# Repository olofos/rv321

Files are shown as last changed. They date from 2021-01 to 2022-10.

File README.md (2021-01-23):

# rv321

rv321 is an RISC-V processor implemented using 74HC series logic. Currently the RV32E base instruction set is supported. The design has been simulated using [hneemann's Digital](https://github.com/hneemann/Digital). The simulated circuit also supports the C and Zicsr extensions, though these are not fully implemented in the hardware. The circuit is highly modular, and support for these extra extensions, or for the full RV32I base instruction set, can easily be added by changing only some of the modules.

The rv321 is implemented with a [bit-serial architecture](https://en.wikipedia.org/wiki/Bit-serial_architecture) where, for example, the ALU acts on one bit at a time. This makes the CPU very slow, each instruction requires around 100 clock cycles. The benefit of this architecture is that a one bit ALU is much smaller than a 32-bit ALU and that internal data paths only require a single line instead of a big parallel bus. This makes it possible to implement various modules as individual components connected through simple cables.

## Supported Instructions

The CPU supports all the instructions of the RV32E as well as the C and Zicsr extensions. However, the instructions are not completely decoded, which means that some illegal instructions will be incorrectly interpreted as valid instructions. This mostly affect instruction encodings that are not defined in the RISC-V specification. However, a few encodings that are valid RISC-V instructions, such as `sret` and `uret` will be erroneously decoded instead of raising an illegal instruction exception, even though these instructions are illegal since code on rv321 only runs in machine mode.

## CSRs

Currently the following CSRs are implemented:

* `mstatus`
* `mepc`
* `mtvec`
* `mscratch`
* `mcause`
* `mip`
* `mie`

All other CSRs are read as zero. Note that reading from or writing to an invalid CSR does *not* cause an illegal instruction exception.

## Traps and Interrupts

# Technical Details

The rv321 CPU is microcoded with the code stored in four 128kB parallel flash ROMs. The instructions are decoded by addressing these ROMs by 10 bits of the opcode, together with a six bit step counter and a flag bit, which is used by for example the branch instructions. Each opcode is processed in a number of *steps*, which in turn consist of either one or four *clock cycles*. There are two types of clock cycles: *control cycles* and *bus cycles*. During a control cycle only the control lines are being changed, while bus cycles are used to transfer data along the various internal and external buses. A step with a control cycle is always a single cycle long, but a step with bus cycles can be either one or four cycles long. 

Internal registers are implemented using shift registers that feed back into themselves, effectively creating delay line memories. Because of this, the bus cycles always have to come in groups of 32. Most data transfers are 32 bits and thus automatically take 32 bus cycles to complete anyway. However, there are a couple of cases where a shorter data transfer has to be extended by extra bus cycles to keep the registers in sync. One such examples is storing a single byte to memory, where only 8 cycles are needed for the actual data transfer, but an additional 24 cycles are needed to keep the alignment of the registers (note that a load of an 8 bit byte would always need 32 bus cycles since we need to fill the upper 24 bit with either zeros or the sign extension of the loaded byte). A second example is when transferring a 12 bit CSR address, where a padding of 20 cycles is necessary. These extra dummy bus cycles could have been avoided by gating the bus clock to registers that are not involved in the transfer, but the current design saves a bit of complexity by not introducing extra clock gates and control lines to drive them. 

## The ALU

The ALU supports the following operations:

* Bitwise boolean operations: `and`, `or` and `xor`
* Addition and subtraction
* Comparisons: equality, signed less-than and unsigned less-than
* Logical shift left, logical shift right and arithmetic shift right

The first three sets of operations are fairly straight forward.

The shift operations are more interesting. It does not use a full 32 bit barrel shifter since this would take up quite a bit of space. Instead the HEF4557B variable length shift register is used as intermediate storage during the computation (the same type of shift register is used in several other places in the rv321 as a convenient serial-in serial-out shift register with a fairly large number of bits, but the shifter in the ALU is the only circuitry that takes advantage of the possibility to vary the length of the shift register). The computation of a value shifted left or right by `n` bits goes in several steps:

1. Use the addition circuitry of the ALU to calculate the needed shift register length: `L = 32 + n` for a left shift and `L = 32 - n` for a right shift
1. Configure the HEF4557B shift register to be `L` bits long and clear its content
1. Shift in 32 bits of input data into the shift register
1. Shift out 32 bits of output data from the shift register

If the shift register length `L` is less than 32 (as is the case for a right shift with `n > 0`) we fill the remaining bits with either zero for a logical shift, or with the top bit of the output (the sign bit) for an arithmetic shift. The sign bit is stored in an extra flip flop which is set in the previous step.

As an example let us shift `0x87654321` by 12 bits to the left

1. The length of the shift register is `L = 32 + 12 = 44`.
1. The shift register is cleared. Its content is `0x00000000000`.
1. We shift in our 32 bits of data, starting with the least significant bit. After this the content of the shift register is `0x87654321000`.
1. We shift out 32 bits of output data, starting with the least significant bit. The result is the bottom four bytes of the shift register, `0x54321000`, which is exactly the expected result. The shift register still contains `0x00000000876`, but these bits are never used.

As a second example let us take the arithmetical shift `0x87654321` by 12 bits to the right

1. The length of the shift register is `L = 32 - 12 = 20`.
1. The shift register is cleared. Its content is `0x00000`.
1. We shift in our 32 bits of data, starting with the least significant bit. After this the content of the shift register is `0x87654`. Note that the lowest 12 bits have been discarded since they did not fit in the register.
1. We shift out 32 bits of output data, starting with the least significant bit. Since the shift register now contains less than 32 bits, we repeatedly shift in the sign bit of the input, which is our case is one. The resulting output is `0xFFF87654`, which again is the expected result. The shift register is left containing `0xFFFFF`.

## Possible Optimisations

The bit-serial architecture makes the rv321 CPU very inefficient. However, there is room for optimisation of the current implementation. There are two main steps for each instruction. First the instruction is fetched and then it is executed. The fetching is exactly the same for all instructions. It would be more efficient to begin fetching the next instruction while executing the previous instruction. This would make any instruction that does not affect the program counter or access memory run faster. However, this would require a more complicated reset circuit, to ensure that the very first instruction is properly fetched, and some parts of the circuit are made simpler by the fact that each instruction has a well-defined start and end. Moreover, the program counter is currently always routed through the ALU, so that there is only one source of memory addresses. For the ALU to run simultaneously with the loading of the memory address from the program counter, a new multiplexer would need to be added.

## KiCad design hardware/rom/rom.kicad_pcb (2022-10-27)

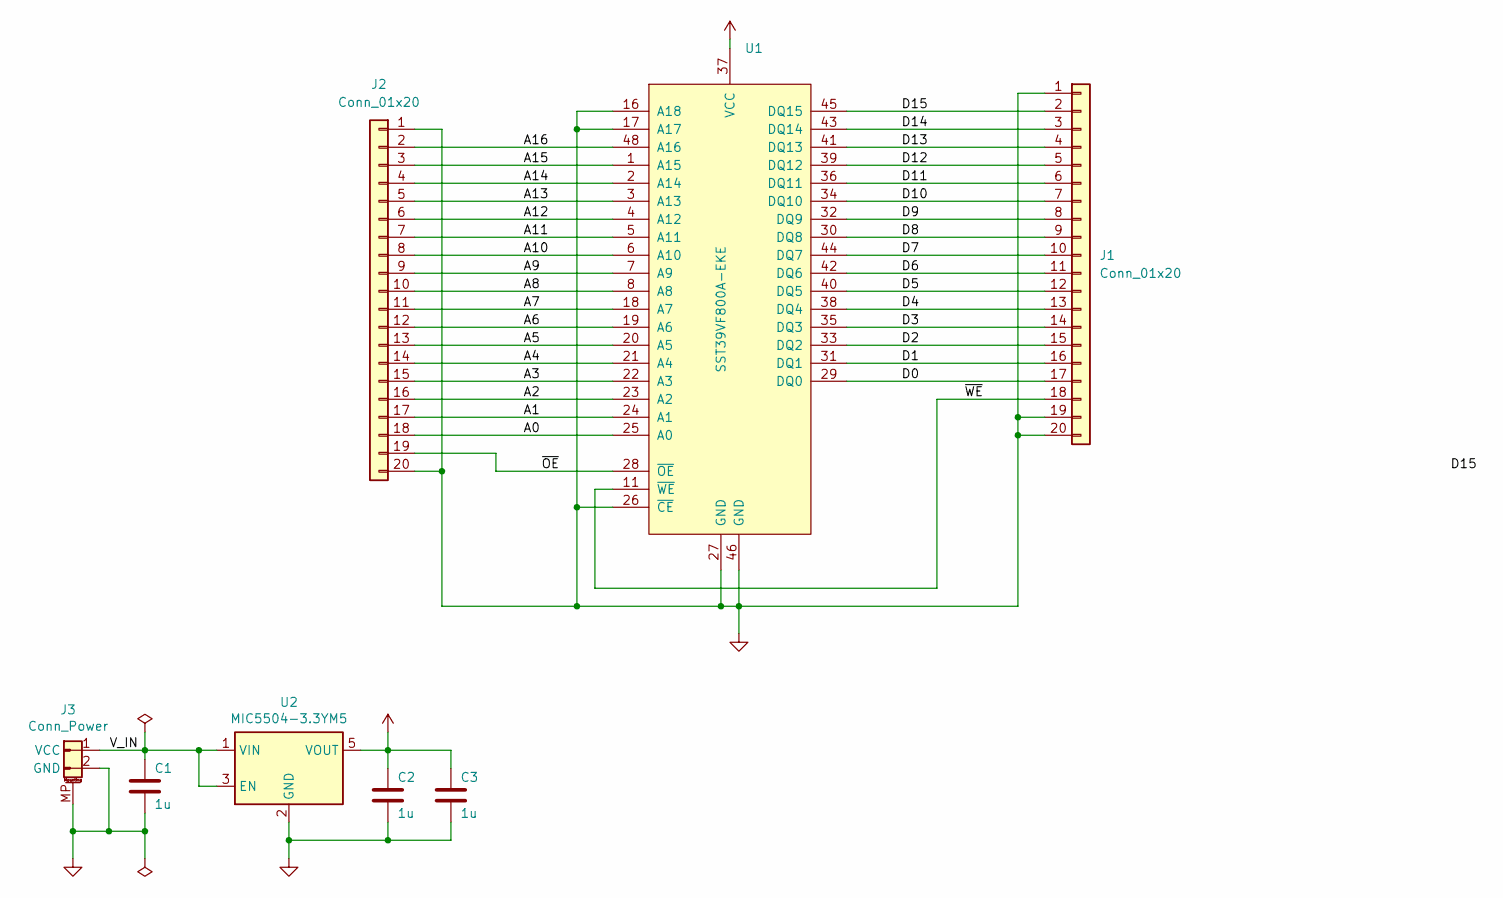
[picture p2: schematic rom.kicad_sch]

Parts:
C1, C2, C3: 1u; C_0805_2012Metric_Pad1.18x1.45mm_HandSolder
J1, J2: Conn_01x20; IDC-Header_2x10_P2.54mm_Vertical
J3: Conn_Power; JST_PH_S2B-PH-SM4-TB_1x02-1MP_P2.00mm_Horizontal
U1: SST39VF800A-EKE; TSOP-I-48_18.4x12mm_P0.5mm
U2: MIC5504-3.3YM5; SOT-23-5_HandSoldering

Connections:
/A0: J2.18, U1.25 (A0)
/A1: J2.17, U1.24 (A1)
/A2: J2.16, U1.23 (A2)
/A3: J2.15, U1.22 (A3)
/A4: J2.14, U1.21 (A4)
/A5: J2.13, U1.20 (A5)
/A6: J2.12, U1.19 (A6)
/A7: J2.11, U1.18 (A7)
/A8: J2.10, U1.8 (A8)
/A9: J2.9, U1.7 (A9)
/A10: J2.8, U1.6 (A10)
/A11: J2.7, U1.5 (A11)
/A12: J2.6, U1.4 (A12)
/A13: J2.5, U1.3 (A13)
/A14: J2.4, U1.2 (A14)
/A15: J2.3, U1.1 (A15)
/A16: J2.2, U1.48 (A16)
/D0: J1.17, U1.29 (DQ0)
/D1: J1.16, U1.31 (DQ1)
/D2: J1.15, U1.33 (DQ2)
/D3: J1.14, U1.35 (DQ3)
/D4: J1.13, U1.38 (DQ4)
/D5: J1.12, U1.40 (DQ5)
/D6: J1.11, U1.42 (DQ6)
/D7: J1.10, U1.44 (DQ7)
/D8: J1.9, U1.30 (DQ8)
/D9: J1.8, U1.32 (DQ9)
/D10: J1.7, U1.34 (DQ10)
/D11: J1.6, U1.36 (DQ11)
/D12: J1.5, U1.39 (DQ12)
/D13: J1.4, U1.41 (DQ13)
/D14: J1.3, U1.43 (DQ14)
/D15: J1.2, U1.45 (DQ15)
/V_IN: C1.2, J3.1 (VCC), U2.1 (VIN), U2.3 (EN)
/~OE: J2.19, U1.28 (~OE)
/~WE: J1.18, U1.11 (~WE)
GND: C1.1, C2.1, C3.1, J1.1, J1.19, J1.20, J2.1, J2.20, J3.2 (GND), J3.MP, U1.16 (A18), U1.17 (A17), U1.26 (~CE), U1.27 (GND), U1.46 (GND), U2.2 (GND)
VCC: C2.2, C3.2, U1.37 (VCC), U2.5 (VOUT)

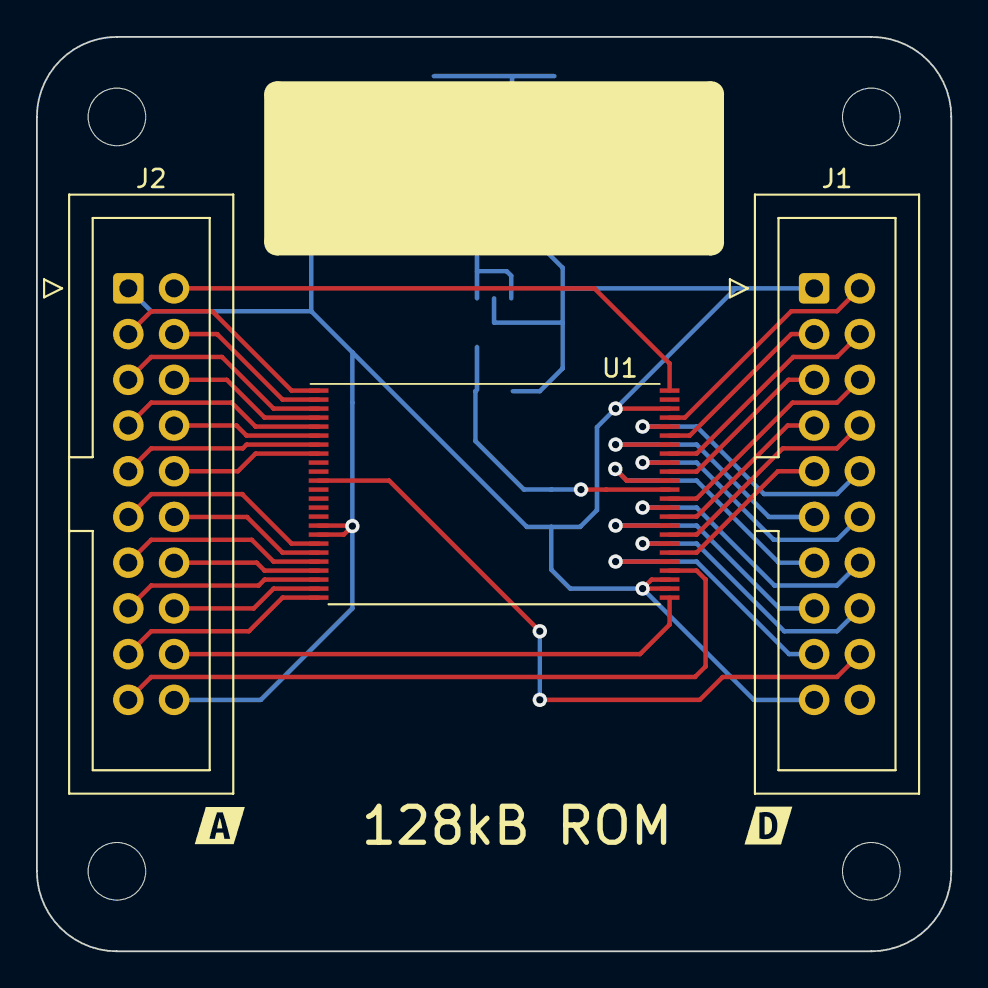
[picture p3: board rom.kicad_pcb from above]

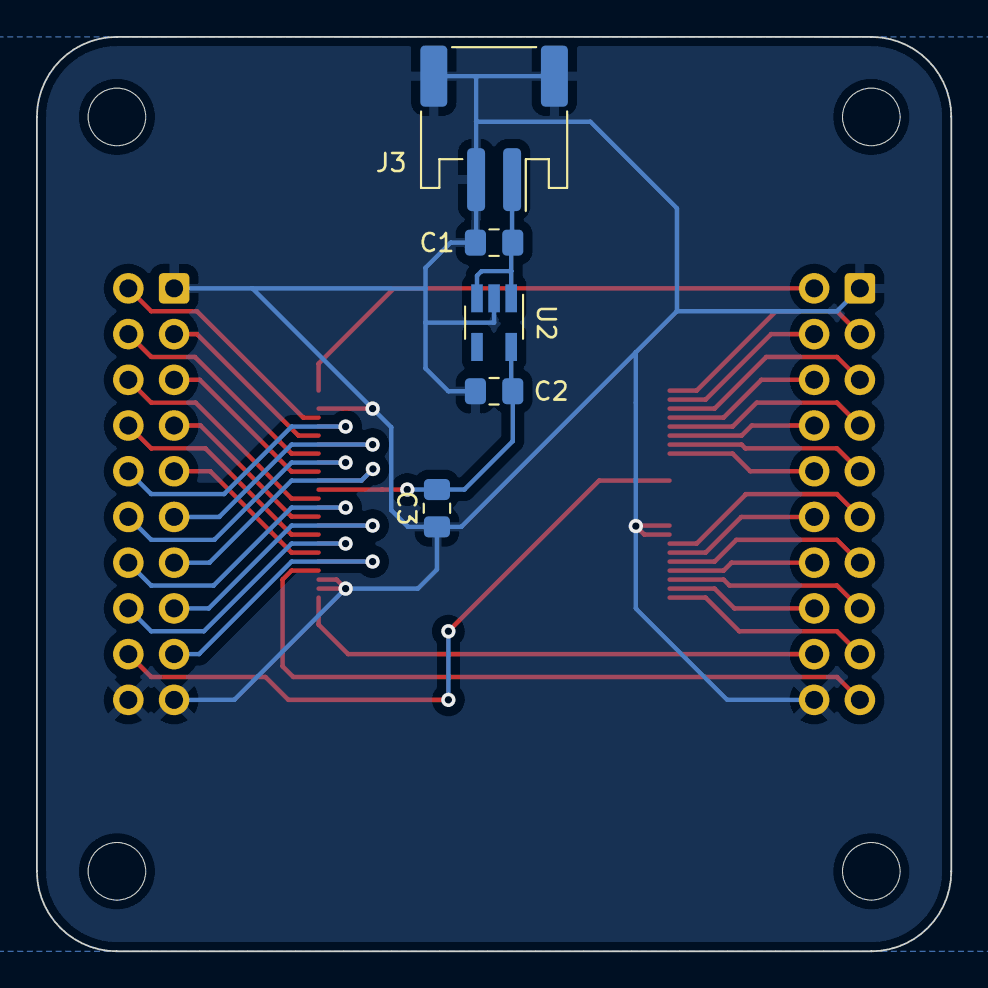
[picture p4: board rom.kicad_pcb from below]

Board: 2 copper layers, 50.8 x 50.8 mm, 10 parts (5 on the bottom side), 38 nets.

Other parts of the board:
kibuzzard-635AED85: G***; kibuzzard-635AED85
kibuzzard-635AED97: G***; kibuzzard-635AED97

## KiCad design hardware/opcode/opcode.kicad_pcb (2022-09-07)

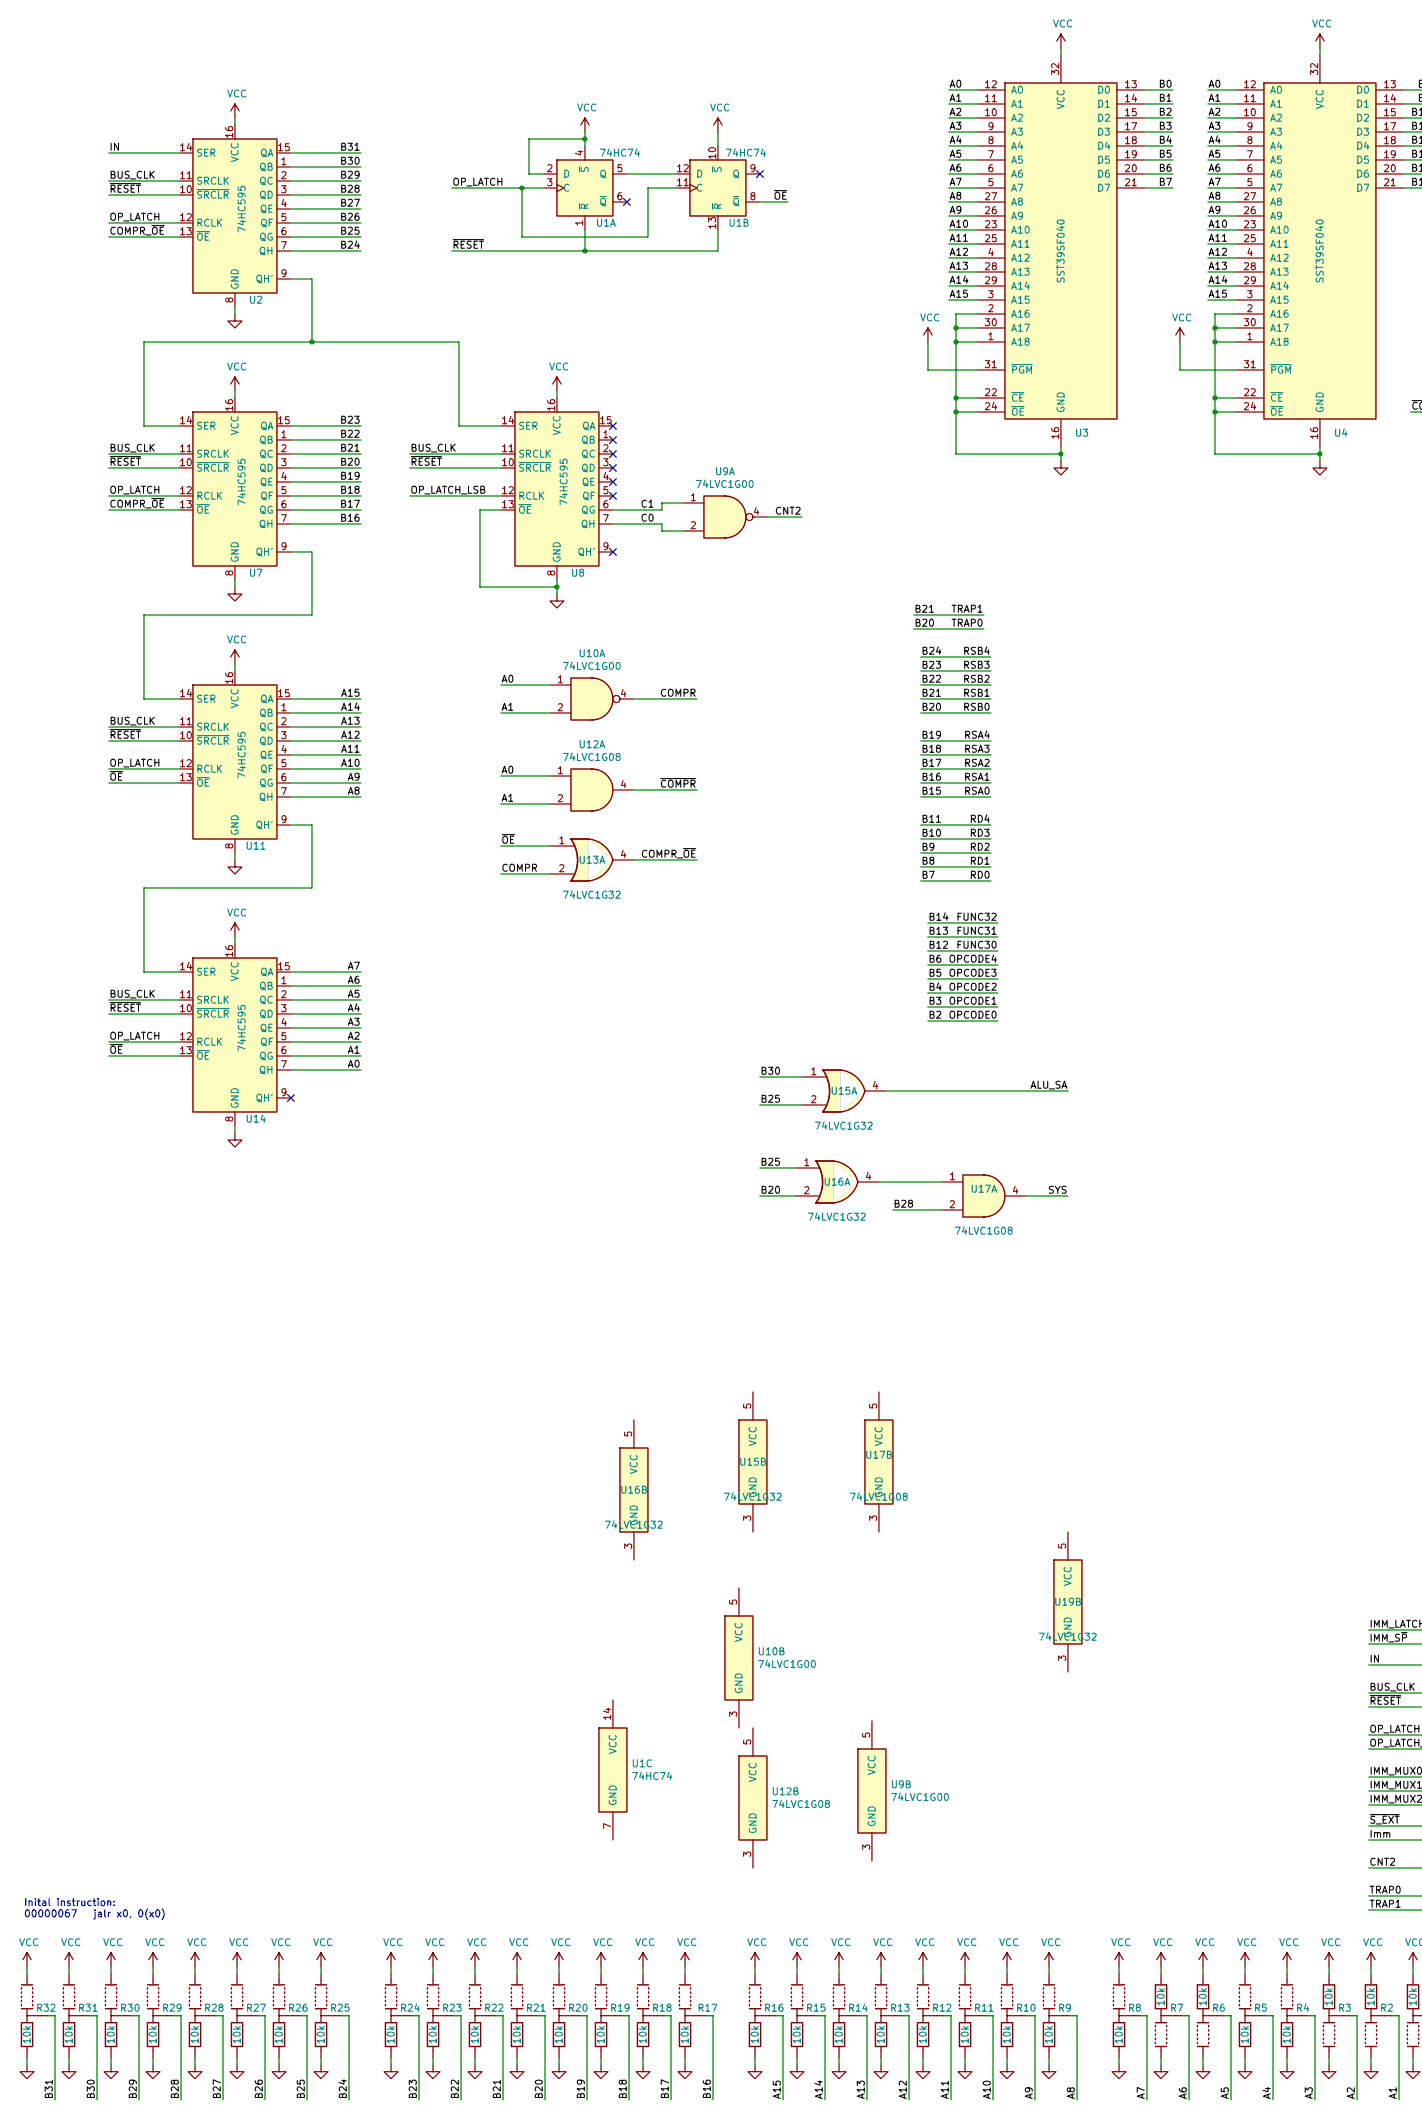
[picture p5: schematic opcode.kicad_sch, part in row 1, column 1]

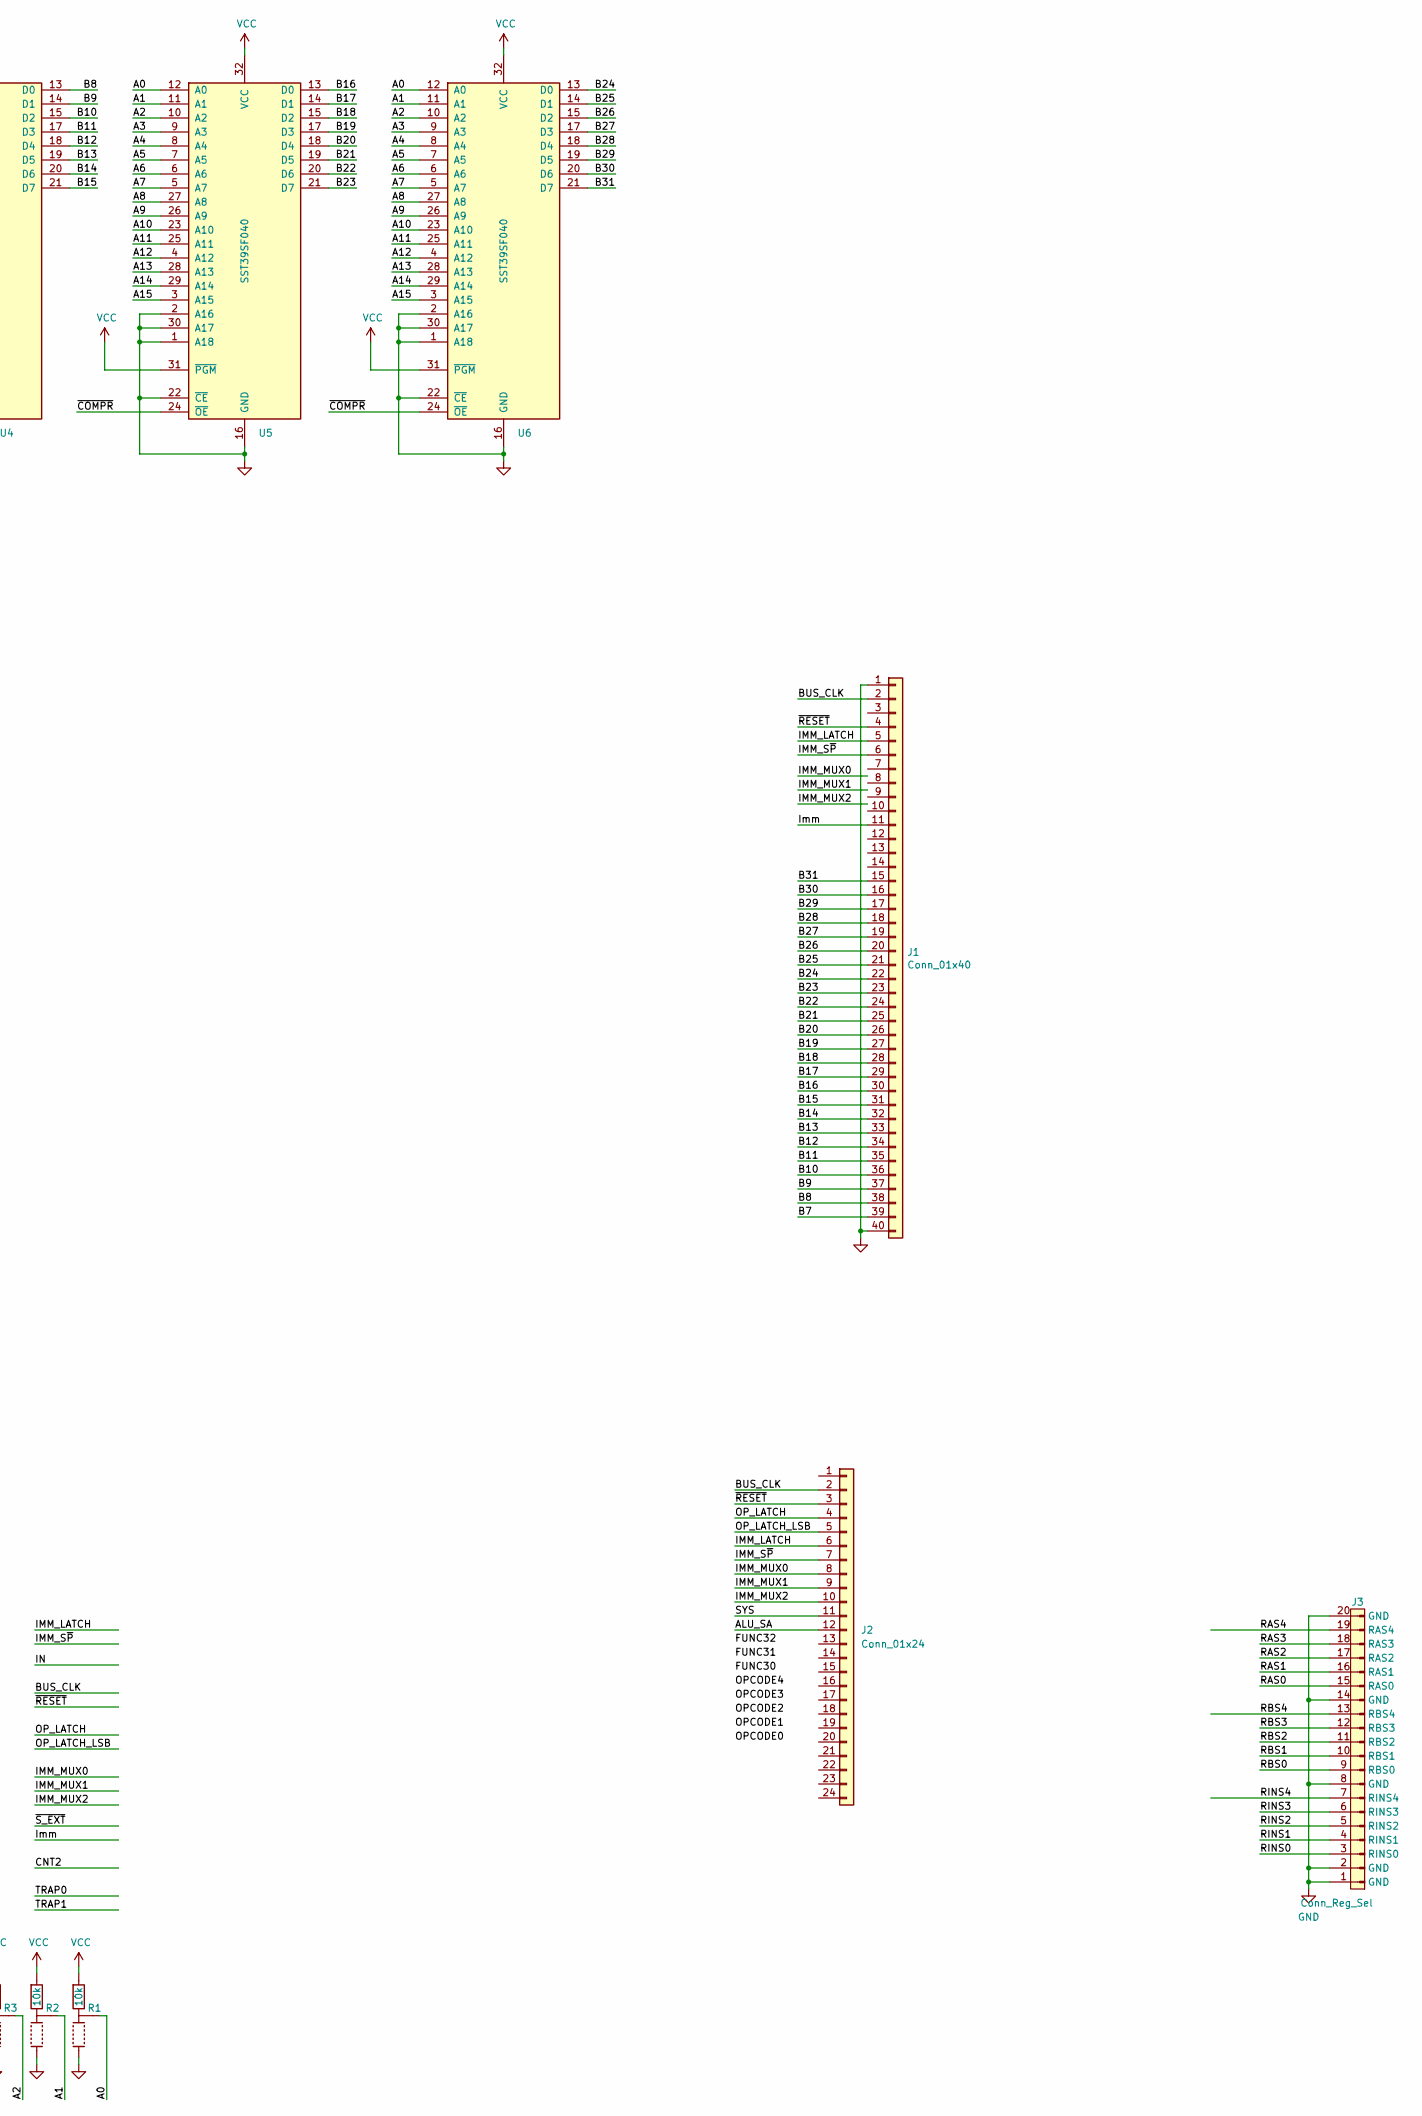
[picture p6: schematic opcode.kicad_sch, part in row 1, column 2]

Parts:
J1: Conn_01x40; IDC-Header_2x20_P2.54mm_Vertical
J2: Conn_01x24; IDC-Header_2x12_P2.54mm_Vertical
J3: Conn_Reg_Sel; IDC-Header_2x10_P2.54mm_Vertical
R1, R2, R3, R4, R5, R6, R7, R8, R9, R10, R11, R12, R13, R14, R15, R16, R17, R18, R19, R20, R21, R22, R23, R24, R25, R26, R27, R28, R29, R30, R31, R32: 10k; Jumper_3_R_0805
U1: 74HC74; SOIC-14_3.9x8.7mm_P1.27mm
U2, U7, U8, U11, U14: 74HC595; SOIC-16_3.9x9.9mm_P1.27mm
U3, U4, U5, U6: SST39SF040; PLCC-32-socket-2M-8432-11B1-RK-TP
U9, U10: 74LVC1G00; SOT-23-5_HandSoldering
U12, U17: 74LVC1G08; SOT-23-5_HandSoldering
U13, U15, U16, U19: 74LVC1G32; SOT-23-5_HandSoldering

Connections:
/A0: R1.2, U3.12 (A0), U4.12 (A0), U5.12 (A0), U6.12 (A0), U10.1, U12.1, U14.7 (QH)
/A1: R2.2, U3.11 (A1), U4.11 (A1), U5.11 (A1), U6.11 (A1), U10.2, U12.2, U14.6 (QG)
/A2: R3.2, U3.10 (A2), U4.10 (A2), U5.10 (A2), U6.10 (A2), U14.5 (QF)
/A3: R4.2, U3.9 (A3), U4.9 (A3), U5.9 (A3), U6.9 (A3), U14.4 (QE)
/A4: R5.2, U3.8 (A4), U4.8 (A4), U5.8 (A4), U6.8 (A4), U14.3 (QD)
/A5: R6.2, U3.7 (A5), U4.7 (A5), U5.7 (A5), U6.7 (A5), U14.2 (QC)
/A6: R7.2, U3.6 (A6), U4.6 (A6), U5.6 (A6), U6.6 (A6), U14.1 (QB)
/A7: R8.2, U3.5 (A7), U4.5 (A7), U5.5 (A7), U6.5 (A7), U14.15 (QA)
/A8: R9.2, U3.27 (A8), U4.27 (A8), U5.27 (A8), U6.27 (A8), U11.7 (QH)
/A9: R10.2, U3.26 (A9), U4.26 (A9), U5.26 (A9), U6.26 (A9), U11.6 (QG)
/A10: R11.2, U3.23 (A10), U4.23 (A10), U5.23 (A10), U6.23 (A10), U11.5 (QF)
/A11: R12.2, U3.25 (A11), U4.25 (A11), U5.25 (A11), U6.25 (A11), U11.4 (QE)
/A12: R13.2, U3.4 (A12), U4.4 (A12), U5.4 (A12), U6.4 (A12), U11.3 (QD)
/A13: R14.2, U3.28 (A13), U4.28 (A13), U5.28 (A13), U6.28 (A13), U11.2 (QC)
/A14: R15.2, U3.29 (A14), U4.29 (A14), U5.29 (A14), U6.29 (A14), U11.1 (QB)
/A15: R16.2, U3.3 (A15), U4.3 (A15), U5.3 (A15), U6.3 (A15), U11.15 (QA)
/ALU_SA: J2.12, U15.4
/B0: U3.13 (D0)
/B1: U3.14 (D1)
/B2: U3.15 (D2)
/B3: U3.17 (D3)
/B4: U3.18 (D4)
/B5: U3.19 (D5)
/B6: U3.20 (D6)
/B7: J1.39, U3.21 (D7)
/B8: J1.38, U4.13 (D0)
/B9: J1.37, U4.14 (D1)
/B10: J1.36, U4.15 (D2)
/B11: J1.35, U4.17 (D3)
/B12: J1.34, U4.18 (D4)
/B13: J1.33, U4.19 (D5)
/B14: J1.32, U4.20 (D6)
/B15: J1.31, U4.21 (D7)
/B16: J1.30, R17.2, U5.13 (D0), U7.7 (QH)
/B17: J1.29, R18.2, U5.14 (D1), U7.6 (QG)
/B18: J1.28, R19.2, U5.15 (D2), U7.5 (QF)
/B19: J1.27, R20.2, U5.17 (D3), U7.4 (QE)
/B20: J1.26, R21.2, U5.18 (D4), U7.3 (QD), U16.2
/B21: J1.25, R22.2, U5.19 (D5), U7.2 (QC)
/B22: J1.24, R23.2, U5.20 (D6), U7.1 (QB)
/B23: J1.23, R24.2, U5.21 (D7), U7.15 (QA)
/B24: J1.22, R25.2, U2.7 (QH), U6.13 (D0)
/B25: J1.21, R26.2, U2.6 (QG), U6.14 (D1), U15.2, U16.1
/B26: J1.20, R27.2, U2.5 (QF), U6.15 (D2)
/B27: J1.19, R28.2, U2.4 (QE), U6.17 (D3)
/B28: J1.18, R29.2, U2.3 (QD), U6.18 (D4), U17.2
/B29: J1.17, R30.2, U2.2 (QC), U6.19 (D5)
/B30: J1.16, R31.2, U2.1 (QB), U6.20 (D6), U15.1
/B31: J1.15, R32.2, U2.15 (QA), U6.21 (D7)
/BUS_CLK: J1.2, J2.2, U2.11 (SRCLK), U7.11 (SRCLK), U8.11 (SRCLK), U11.11 (SRCLK), U14.11 (SRCLK)
/C0: U8.7 (QH), U9.2
/C1: U8.6 (QG), U9.1
/CNT2: U9.4
/COMPR: U10.4, U13.2
/COMPR_~OE: U2.13 (~OE), U7.13 (~OE), U13.4
/IMM_LATCH: J1.5, J2.6
/IMM_MUX0: J2.8
/IMM_MUX1: J2.9
/IMM_MUX2: J2.10
/IMM_S~P: J1.6, J2.7
/IN: U2.14 (SER)
/Imm: J1.11
/OP_LATCH: J2.4, U1.3 (C), U1.11 (C), U2.12 (RCLK), U7.12 (RCLK), U11.12 (RCLK), U14.12 (RCLK)
/OP_LATCH_LSB: J2.5, U8.12 (RCLK)
/RAS0: J3.15 (RAS0)
/RAS1: J3.16 (RAS1)
/RAS2: J3.17 (RAS2)
/RAS3: J3.18 (RAS3)
/RAS4: J3.19 (RAS4)
/RBS0: J3.9 (RBS0)
/RBS1: J3.10 (RBS1)
/RBS2: J3.11 (RBS2)
/RBS3: J3.12 (RBS3)
/RBS4: J3.13 (RBS4)
/RINS0: J3.3 (RINS0)
/RINS1: J3.4 (RINS1)
/RINS2: J3.5 (RINS2)
/RINS3: J3.6 (RINS3)
/RINS4: J3.7 (RINS4)
/SYS: J2.11, U17.4
/~COMPR: U5.24 (~OE), U6.24 (~OE), U12.4
/~OE: U1.8 (~Q), U11.13 (~OE), U13.1, U14.13 (~OE)
/~RESET: J1.4, J2.3, U1.1 (~R), U1.13 (~R), U2.10 (~SRCLR), U7.10 (~SRCLR), U8.10 (~SRCLR), U11.10 (~SRCLR), U14.10 (~SRCLR)
GND: J1.1, J1.40, J3.1 (GND), J3.2 (GND), J3.8 (GND), J3.14 (GND), J3.20 (GND), R1.3, R2.3, R3.3, R4.1, R5.1, R6.3, R7.3, R8.1, R9.1, R10.1, R11.1, R12.1, R13.1, R14.1, R15.1, R16.1, R17.1, R18.1, R19.1, R20.1, R21.1, R22.1, R23.1, R24.1, R25.1, R26.1, R27.1, R28.1, R29.1, R30.1, R31.1, R32.1, U2.8 (GND), U3.1 (A18), U3.2 (A16), U3.16 (GND), U3.22 (~CE), U3.24 (~OE), U3.30 (A17), U4.1 (A18), U4.2 (A16), U4.16 (GND), U4.22 (~CE), U4.24 (~OE), U4.30 (A17), U5.1 (A18), U5.2 (A16), U5.16 (GND), U5.22 (~CE), U5.30 (A17), U6.1 (A18), U6.2 (A16), U6.16 (GND), U6.22 (~CE), U6.30 (A17), U7.8 (GND), U8.8 (GND), U8.13 (~OE), U11.8 (GND), U14.8 (GND)
unnamed: U1.5 (Q), U1.12 (D)
unnamed: U2.9 (QH'), U7.14 (SER), U8.14 (SER)
unnamed: U11.9 (QH'), U14.14 (SER)
unnamed: U7.9 (QH'), U11.14 (SER)
unnamed: U16.4, U17.1
VCC: R1.1, R2.1, R3.1, R4.3, R5.3, R6.1, R7.1, R8.3, R9.3, R10.3, R11.3, R12.3, R13.3, R14.3, R15.3, R16.3, R17.3, R18.3, R19.3, R20.3, R21.3, R22.3, R23.3, R24.3, R25.3, R26.3, R27.3, R28.3, R29.3, R30.3, R31.3, R32.3, U1.2 (D), U1.4 (~S), U1.10 (~S), U2.16 (VCC), U3.31 (~PGM), U3.32 (VCC), U4.31 (~PGM), U4.32 (VCC), U5.31 (~PGM), U5.32 (VCC), U6.31 (~PGM), U6.32 (VCC), U7.16 (VCC), U8.16 (VCC), U11.16 (VCC), U14.16 (VCC)

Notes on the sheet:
Inital instruction: 00000067 jalr x0, 0(x0)

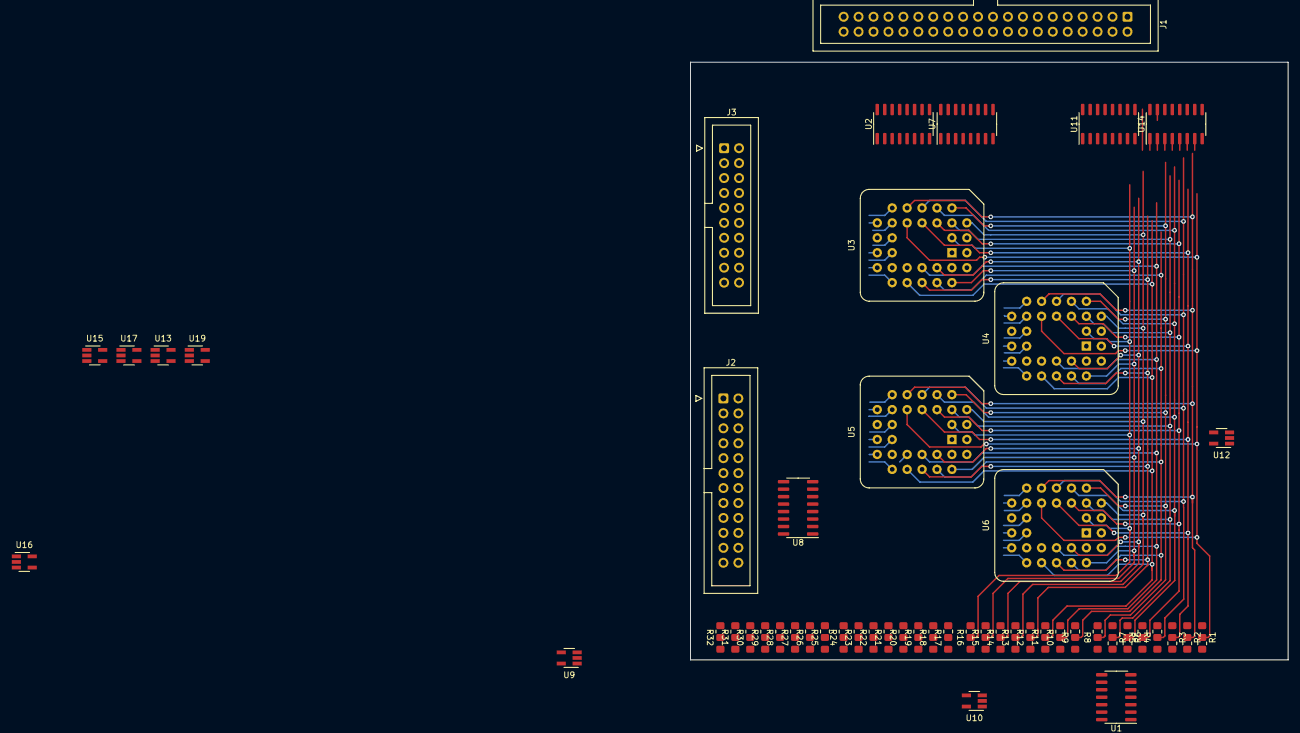
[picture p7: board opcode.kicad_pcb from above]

Board: 4 copper layers, 101.6 x 101.6 mm, 53 parts (0 on the bottom side), 62 nets.

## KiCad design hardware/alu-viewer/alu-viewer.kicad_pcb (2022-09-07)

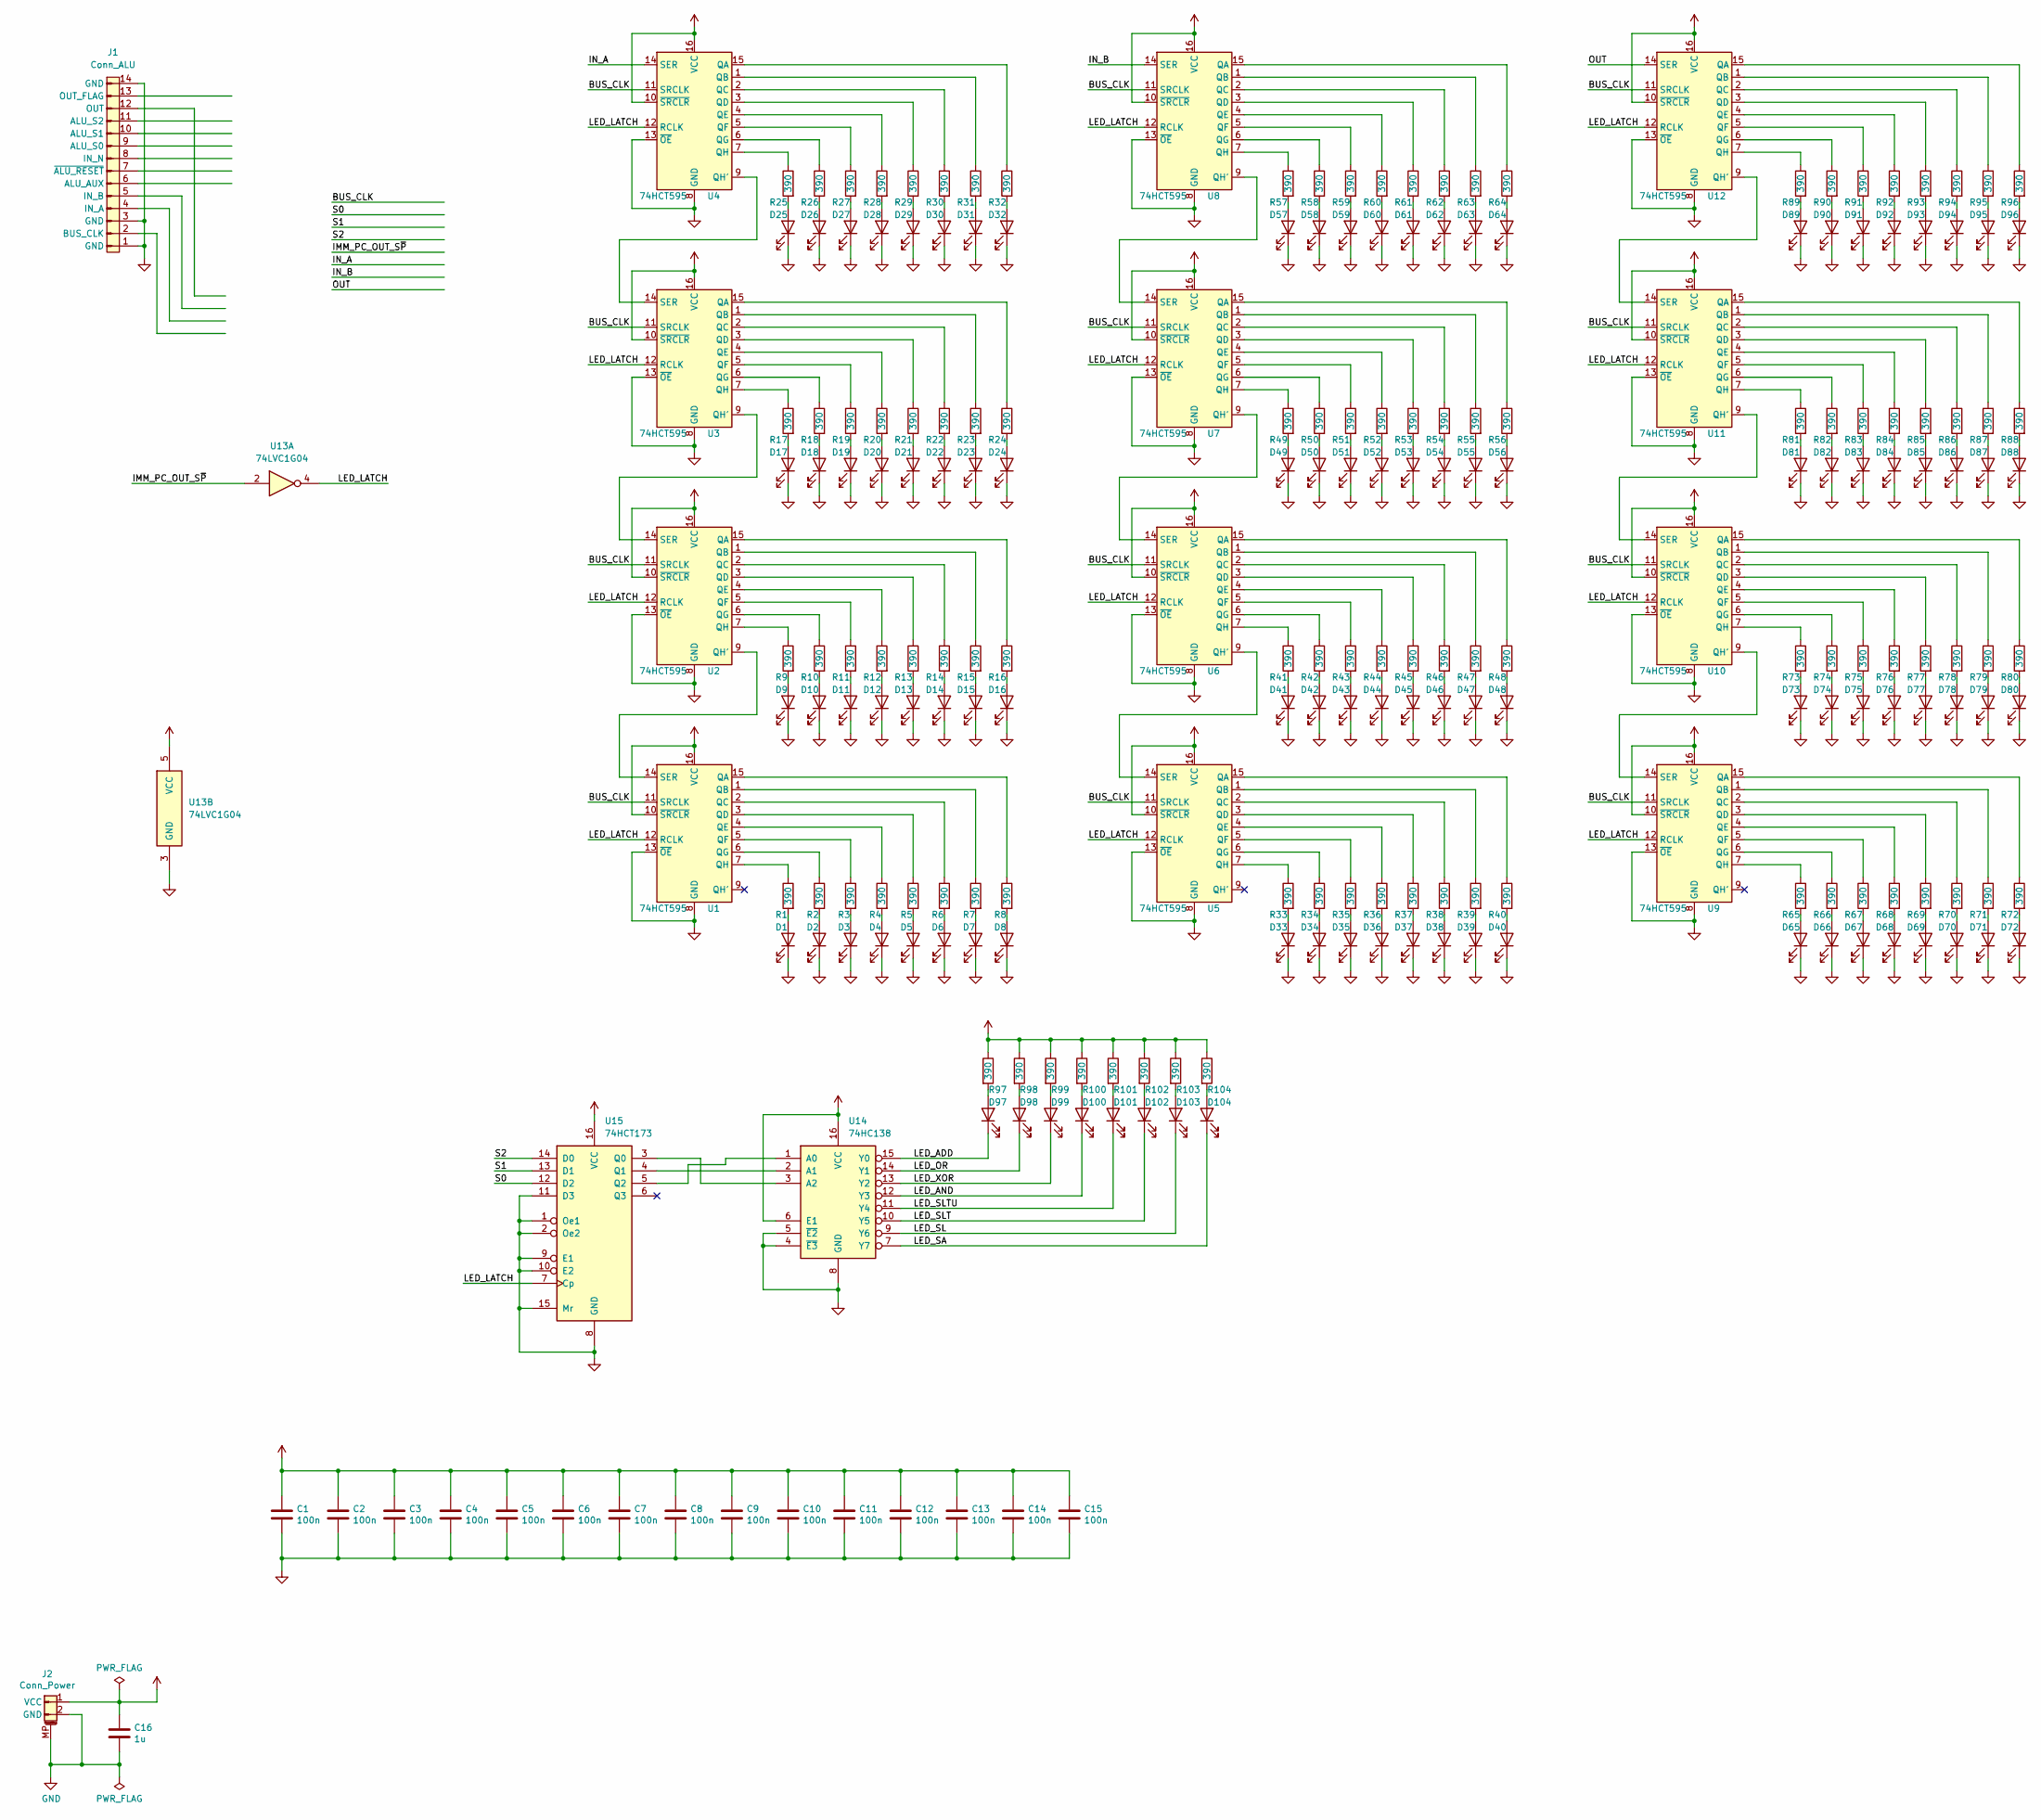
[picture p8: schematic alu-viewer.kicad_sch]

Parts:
C1, C2, C3, C4, C5, C6, C7, C8, C9, C10, C11, C12, C13, C14, C15: 100n; C_0805_2012Metric_Pad1.18x1.45mm_HandSolder
C16: 1u; C_0805_2012Metric_Pad1.18x1.45mm_HandSolder
D1, D2, D3, D4, D5, D6, D7, D8, D9, D10, D11, D12, D13, D14, D15, D16, D17, D18, D19, D20, D21, D22, D23, D24, D25, D26, D27, D28, D29, D30, D31, D32, D33, D34, D35, D36, D37, D38, D39, D40, D41, D42, D43, D44, D45, D46, D47, D48, D49, D50, D51, D52, D53, D54, D55, D56, D57, D58, D59, D60, D61, D62, D63, D64, D65, D66, D67, D68, D69, D70, D71, D72, D73, D74, D75, D76, D77, D78, D79, D80, D81, D82, D83, D84, D85, D86, D87, D88, D89, D90, D91, D92, D93, D94, D95, D96, D97, D98, D99, D100, D101, D102, D103, D104: LED; LED_0603_1608Metric
J1: Conn_ALU
J2: Conn_Power; JST_PH_S2B-PH-SM4-TB_1x02-1MP_P2.00mm_Horizontal
R1, R2, R3, R4, R5, R6, R7, R8, R9, R10, R11, R12, R13, R14, R15, R16, R17, R18, R19, R20, R21, R22, R23, R24, R25, R26, R27, R28, R29, R30, R31, R32, R33, R34, R35, R36, R37, R38, R39, R40, R41, R42, R43, R44, R45, R46, R47, R48, R49, R50, R51, R52, R53, R54, R55, R56, R57, R58, R59, R60, R61, R62, R63, R64, R65, R66, R67, R68, R69, R70, R71, R72, R73, R74, R75, R76, R77, R78, R79, R80, R81, R82, R83, R84, R85, R86, R87, R88, R89, R90, R91, R92, R93, R94, R95, R96, R97, R98, R99, R100, R101, R102, R103, R104: 390; R_0603_1608Metric
U1, U2, U3, U4, U5, U6, U7, U8, U9, U10, U11, U12: 74HCT595; SOIC-16_3.9x9.9mm_P1.27mm
U13: 74LVC1G04; SOT-23-5_HandSoldering
U14: 74HC138; SOIC-16_3.9x9.9mm_P1.27mm
U15: 74HCT173; SOIC-16_3.9x9.9mm_P1.27mm

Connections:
/BUS_CLK: U1.11 (SRCLK), U2.11 (SRCLK), U3.11 (SRCLK), U4.11 (SRCLK), U5.11 (SRCLK), U6.11 (SRCLK), U7.11 (SRCLK), U8.11 (SRCLK), U9.11 (SRCLK), U10.11 (SRCLK), U11.11 (SRCLK), U12.11 (SRCLK)
/IMM_PC_OUT_S~P: U13.2
/IN_A: U4.14 (SER)
/IN_B: U8.14 (SER)
/LED_ADD: D97.1 (K), U14.15 (Y0)
/LED_AND: D100.1 (K), U14.12 (Y3)
/LED_LATCH: U1.12 (RCLK), U2.12 (RCLK), U3.12 (RCLK), U4.12 (RCLK), U5.12 (RCLK), U6.12 (RCLK), U7.12 (RCLK), U8.12 (RCLK), U9.12 (RCLK), U10.12 (RCLK), U11.12 (RCLK), U12.12 (RCLK), U13.4, U15.7 (Cp)
/LED_OR: D98.1 (K), U14.14 (Y1)
/LED_SA: D104.1 (K), U14.7 (Y7)
/LED_SL: D103.1 (K), U14.9 (Y6)
/LED_SLT: D102.1 (K), U14.10 (Y5)
/LED_SLTU: D101.1 (K), U14.11 (Y4)
/LED_XOR: D99.1 (K), U14.13 (Y2)
/OUT: U12.14 (SER)
/S0: U15.12 (D2)
/S1: U15.13 (D1)
/S2: U15.14 (D0)
GND: C1.2, C2.2, C3.2, C4.2, C5.2, C6.2, C7.2, C8.2, C9.2, C10.2, C11.2, C12.2, C13.2, C14.2, C15.2, C16.2, D1.1 (K), D2.1 (K), D3.1 (K), D4.1 (K), D5.1 (K), D6.1 (K), D7.1 (K), D8.1 (K), D9.1 (K), D10.1 (K), D11.1 (K), D12.1 (K), D13.1 (K), D14.1 (K), D15.1 (K), D16.1 (K), D17.1 (K), D18.1 (K), D19.1 (K), D20.1 (K), D21.1 (K), D22.1 (K), D23.1 (K), D24.1 (K), D25.1 (K), D26.1 (K), D27.1 (K), D28.1 (K), D29.1 (K), D30.1 (K), D31.1 (K), D32.1 (K), D33.1 (K), D34.1 (K), D35.1 (K), D36.1 (K), D37.1 (K), D38.1 (K), D39.1 (K), D40.1 (K), D41.1 (K), D42.1 (K), D43.1 (K), D44.1 (K), D45.1 (K), D46.1 (K), D47.1 (K), D48.1 (K), D49.1 (K), D50.1 (K), D51.1 (K), D52.1 (K), D53.1 (K), D54.1 (K), D55.1 (K), D56.1 (K), D57.1 (K), D58.1 (K), D59.1 (K), D60.1 (K), D61.1 (K), D62.1 (K), D63.1 (K), D64.1 (K), D65.1 (K), D66.1 (K), D67.1 (K), D68.1 (K), D69.1 (K), D70.1 (K), D71.1 (K), D72.1 (K), D73.1 (K), D74.1 (K), D75.1 (K), D76.1 (K), D77.1 (K), D78.1 (K), D79.1 (K), D80.1 (K), D81.1 (K), D82.1 (K), D83.1 (K), D84.1 (K), D85.1 (K), D86.1 (K), D87.1 (K), D88.1 (K), D89.1 (K), D90.1 (K), D91.1 (K), D92.1 (K), D93.1 (K), D94.1 (K), D95.1 (K), D96.1 (K), J1.1 (GND), J1.3 (GND), J1.14 (GND), J2.2 (GND), J2.MP, U1.8 (GND), U1.13 (~OE), U2.8 (GND), U2.13 (~OE), U3.8 (GND), U3.13 (~OE), U4.8 (GND), U4.13 (~OE), U5.8 (GND), U5.13 (~OE), U6.8 (GND), U6.13 (~OE), U7.8 (GND), U7.13 (~OE), U8.8 (GND), U8.13 (~OE), U9.8 (GND), U9.13 (~OE), U10.8 (GND), U10.13 (~OE), U11.8 (GND), U11.13 (~OE), U12.8 (GND), U12.13 (~OE), U13.3 (GND), U14.4 (~E3), U14.5 (~E2), U14.8 (GND), U15.1 (Oe1), U15.2 (Oe2), U15.8 (GND), U15.9 (E1), U15.10 (E2), U15.11 (D3), U15.15 (Mr)
unnamed: D1.2 (A), R1.2
unnamed: D2.2 (A), R2.2
unnamed: D3.2 (A), R3.2
unnamed: D4.2 (A), R4.2
unnamed: D5.2 (A), R5.2
unnamed: D6.2 (A), R6.2
unnamed: D7.2 (A), R7.2
unnamed: D8.2 (A), R8.2
unnamed: D9.2 (A), R9.2
unnamed: D10.2 (A), R10.2
unnamed: D11.2 (A), R11.2
unnamed: D12.2 (A), R12.2
unnamed: D13.2 (A), R13.2
unnamed: D14.2 (A), R14.2
unnamed: D15.2 (A), R15.2
unnamed: D16.2 (A), R16.2
unnamed: D17.2 (A), R17.2
unnamed: D18.2 (A), R18.2
unnamed: D19.2 (A), R19.2
unnamed: D20.2 (A), R20.2
unnamed: D21.2 (A), R21.2
unnamed: D22.2 (A), R22.2
unnamed: D23.2 (A), R23.2
unnamed: D25.2 (A), R25.2
unnamed: D26.2 (A), R26.2
unnamed: D27.2 (A), R27.2
unnamed: D28.2 (A), R28.2
unnamed: D29.2 (A), R29.2
unnamed: D30.2 (A), R30.2
unnamed: D31.2 (A), R31.2
unnamed: D33.2 (A), R33.2
unnamed: D34.2 (A), R34.2
unnamed: D35.2 (A), R35.2
unnamed: D36.2 (A), R36.2
unnamed: D37.2 (A), R37.2
unnamed: D38.2 (A), R38.2
unnamed: D39.2 (A), R39.2
unnamed: D40.2 (A), R40.2
unnamed: D41.2 (A), R41.2
unnamed: D42.2 (A), R42.2
unnamed: D43.2 (A), R43.2
unnamed: D44.2 (A), R44.2
unnamed: D45.2 (A), R45.2
unnamed: D46.2 (A), R46.2
unnamed: D47.2 (A), R47.2
unnamed: D49.2 (A), R49.2
unnamed: D50.2 (A), R50.2
unnamed: D51.2 (A), R51.2
unnamed: D52.2 (A), R52.2
unnamed: D53.2 (A), R53.2
unnamed: D54.2 (A), R54.2
unnamed: D55.2 (A), R55.2
unnamed: D56.2 (A), R56.2
unnamed: D57.2 (A), R57.2
unnamed: D58.2 (A), R58.2
unnamed: D59.2 (A), R59.2
unnamed: D60.2 (A), R60.2
unnamed: D61.2 (A), R61.2
unnamed: D62.2 (A), R62.2
unnamed: D63.2 (A), R63.2
unnamed: D64.2 (A), R64.2
unnamed: D65.2 (A), R65.2
unnamed: D66.2 (A), R66.2
unnamed: D67.2 (A), R67.2
unnamed: D68.2 (A), R68.2
unnamed: D69.2 (A), R69.2
unnamed: D70.2 (A), R70.2
unnamed: D71.2 (A), R71.2
unnamed: D73.2 (A), R73.2
unnamed: D74.2 (A), R74.2
unnamed: D75.2 (A), R75.2
unnamed: D76.2 (A), R76.2
unnamed: D77.2 (A), R77.2
unnamed: D78.2 (A), R78.2
unnamed: D79.2 (A), R79.2
unnamed: D80.2 (A), R80.2
unnamed: D81.2 (A), R81.2
unnamed: D82.2 (A), R82.2
unnamed: D83.2 (A), R83.2
unnamed: D84.2 (A), R84.2
unnamed: D85.2 (A), R85.2
unnamed: D86.2 (A), R86.2
unnamed: D87.2 (A), R87.2
unnamed: D88.2 (A), R88.2
unnamed: D89.2 (A), R89.2
unnamed: D90.2 (A), R90.2
unnamed: D91.2 (A), R91.2
unnamed: D92.2 (A), R92.2
unnamed: D93.2 (A), R93.2
unnamed: D94.2 (A), R94.2
unnamed: D95.2 (A), R95.2
unnamed: D96.2 (A), R96.2
unnamed: D97.2 (A), R97.2
unnamed: D98.2 (A), R98.2
unnamed: D99.2 (A), R99.2
unnamed: D100.2 (A), R100.2
unnamed: D101.2 (A), R101.2
unnamed: D102.2 (A), R102.2
unnamed: D103.2 (A), R103.2
unnamed: D104.2 (A), R104.2
unnamed: R9.1, U2.7 (QH)
unnamed: R10.1, U2.6 (QG)
unnamed: R11.1, U2.5 (QF)
unnamed: R12.1, U2.4 (QE)
unnamed: R13.1, U2.3 (QD)
unnamed: R14.1, U2.2 (QC)
unnamed: R15.1, U2.1 (QB)
unnamed: R16.1, U2.15 (QA)
unnamed: R17.1, U3.7 (QH)
unnamed: R18.1, U3.6 (QG)
unnamed: R19.1, U3.5 (QF)
unnamed: R20.1, U3.4 (QE)
unnamed: R21.1, U3.3 (QD)
unnamed: R22.1, U3.2 (QC)
unnamed: R23.1, U3.1 (QB)
unnamed: R24.1, U3.15 (QA)
unnamed: D24.2 (A), R24.2
unnamed: R25.1, U4.7 (QH)
unnamed: R26.1, U4.6 (QG)
unnamed: R27.1, U4.5 (QF)
unnamed: R28.1, U4.4 (QE)
unnamed: R29.1, U4.3 (QD)
unnamed: R30.1, U4.2 (QC)
unnamed: R31.1, U4.1 (QB)
unnamed: R32.1, U4.15 (QA)
unnamed: D32.2 (A), R32.2
unnamed: R33.1, U5.7 (QH)
unnamed: R34.1, U5.6 (QG)
unnamed: R35.1, U5.5 (QF)
unnamed: R36.1, U5.4 (QE)
unnamed: R37.1, U5.3 (QD)
unnamed: R38.1, U5.2 (QC)
unnamed: R39.1, U5.1 (QB)
unnamed: R40.1, U5.15 (QA)
unnamed: R41.1, U6.7 (QH)
unnamed: R42.1, U6.6 (QG)
unnamed: R43.1, U6.5 (QF)
unnamed: R44.1, U6.4 (QE)
unnamed: R45.1, U6.3 (QD)
unnamed: R46.1, U6.2 (QC)
unnamed: R47.1, U6.1 (QB)
unnamed: R48.1, U6.15 (QA)
unnamed: D48.2 (A), R48.2
unnamed: R49.1, U7.7 (QH)
unnamed: R50.1, U7.6 (QG)
unnamed: R51.1, U7.5 (QF)
unnamed: R52.1, U7.4 (QE)
unnamed: R53.1, U7.3 (QD)
unnamed: R54.1, U7.2 (QC)
unnamed: R55.1, U7.1 (QB)
unnamed: R56.1, U7.15 (QA)
unnamed: R57.1, U8.7 (QH)
unnamed: R58.1, U8.6 (QG)
unnamed: R59.1, U8.5 (QF)
unnamed: R60.1, U8.4 (QE)
unnamed: R61.1, U8.3 (QD)
unnamed: R62.1, U8.2 (QC)
unnamed: R63.1, U8.1 (QB)
unnamed: R64.1, U8.15 (QA)
unnamed: R65.1, U9.7 (QH)
unnamed: R66.1, U9.6 (QG)
unnamed: R67.1, U9.5 (QF)
unnamed: R68.1, U9.4 (QE)
unnamed: R69.1, U9.3 (QD)
unnamed: R70.1, U9.2 (QC)
unnamed: R71.1, U9.1 (QB)
unnamed: R72.1, U9.15 (QA)
unnamed: D72.2 (A), R72.2
unnamed: R73.1, U10.7 (QH)
unnamed: R74.1, U10.6 (QG)
unnamed: R75.1, U10.5 (QF)
unnamed: R76.1, U10.4 (QE)
unnamed: R77.1, U10.3 (QD)
unnamed: R78.1, U10.2 (QC)
unnamed: R79.1, U10.1 (QB)
unnamed: R80.1, U10.15 (QA)
unnamed: R81.1, U11.7 (QH)
unnamed: R82.1, U11.6 (QG)
unnamed: R83.1, U11.5 (QF)
unnamed: R84.1, U11.4 (QE)
unnamed: R85.1, U11.3 (QD)
unnamed: R86.1, U11.2 (QC)
unnamed: R87.1, U11.1 (QB)
unnamed: R88.1, U11.15 (QA)
unnamed: R89.1, U12.7 (QH)
unnamed: R90.1, U12.6 (QG)
unnamed: R91.1, U12.5 (QF)
unnamed: R92.1, U12.4 (QE)
unnamed: R93.1, U12.3 (QD)
unnamed: R94.1, U12.2 (QC)
unnamed: R95.1, U12.1 (QB)
unnamed: R96.1, U12.15 (QA)
unnamed: R7.1, U1.1 (QB)
unnamed: R6.1, U1.2 (QC)
unnamed: R5.1, U1.3 (QD)
unnamed: R4.1, U1.4 (QE)
unnamed: R3.1, U1.5 (QF)
unnamed: R2.1, U1.6 (QG)
unnamed: R1.1, U1.7 (QH)
unnamed: U1.14 (SER), U2.9 (QH')
unnamed: R8.1, U1.15 (QA)
unnamed: U2.14 (SER), U3.9 (QH')
unnamed: U3.14 (SER), U4.9 (QH')
unnamed: U5.14 (SER), U6.9 (QH')
unnamed: U6.14 (SER), U7.9 (QH')
unnamed: U7.14 (SER), U8.9 (QH')
unnamed: U9.14 (SER), U10.9 (QH')
unnamed: U10.14 (SER), U11.9 (QH')
unnamed: U11.14 (SER), U12.9 (QH')
unnamed: U14.1 (A0), U15.5 (Q2)
unnamed: U14.2 (A1), U15.4 (Q1)
unnamed: U14.3 (A2), U15.3 (Q0)
VCC: C1.1, C2.1, C3.1, C4.1, C5.1, C6.1, C7.1, C8.1, C9.1, C10.1, C11.1, C12.1, C13.1, C14.1, C15.1, C16.1, J2.1 (VCC), R97.1, R98.1, R99.1, R100.1, R101.1, R102.1, R103.1, R104.1, U1.10 (~SRCLR), U1.16 (VCC), U2.10 (~SRCLR), U2.16 (VCC), U3.10 (~SRCLR), U3.16 (VCC), U4.10 (~SRCLR), U4.16 (VCC), U5.10 (~SRCLR), U5.16 (VCC), U6.10 (~SRCLR), U6.16 (VCC), U7.10 (~SRCLR), U7.16 (VCC), U8.10 (~SRCLR), U8.16 (VCC), U9.10 (~SRCLR), U9.16 (VCC), U10.10 (~SRCLR), U10.16 (VCC), U11.10 (~SRCLR), U11.16 (VCC), U12.10 (~SRCLR), U12.16 (VCC), U13.5 (VCC), U14.6 (E1), U14.16 (VCC), U15.16 (VCC)

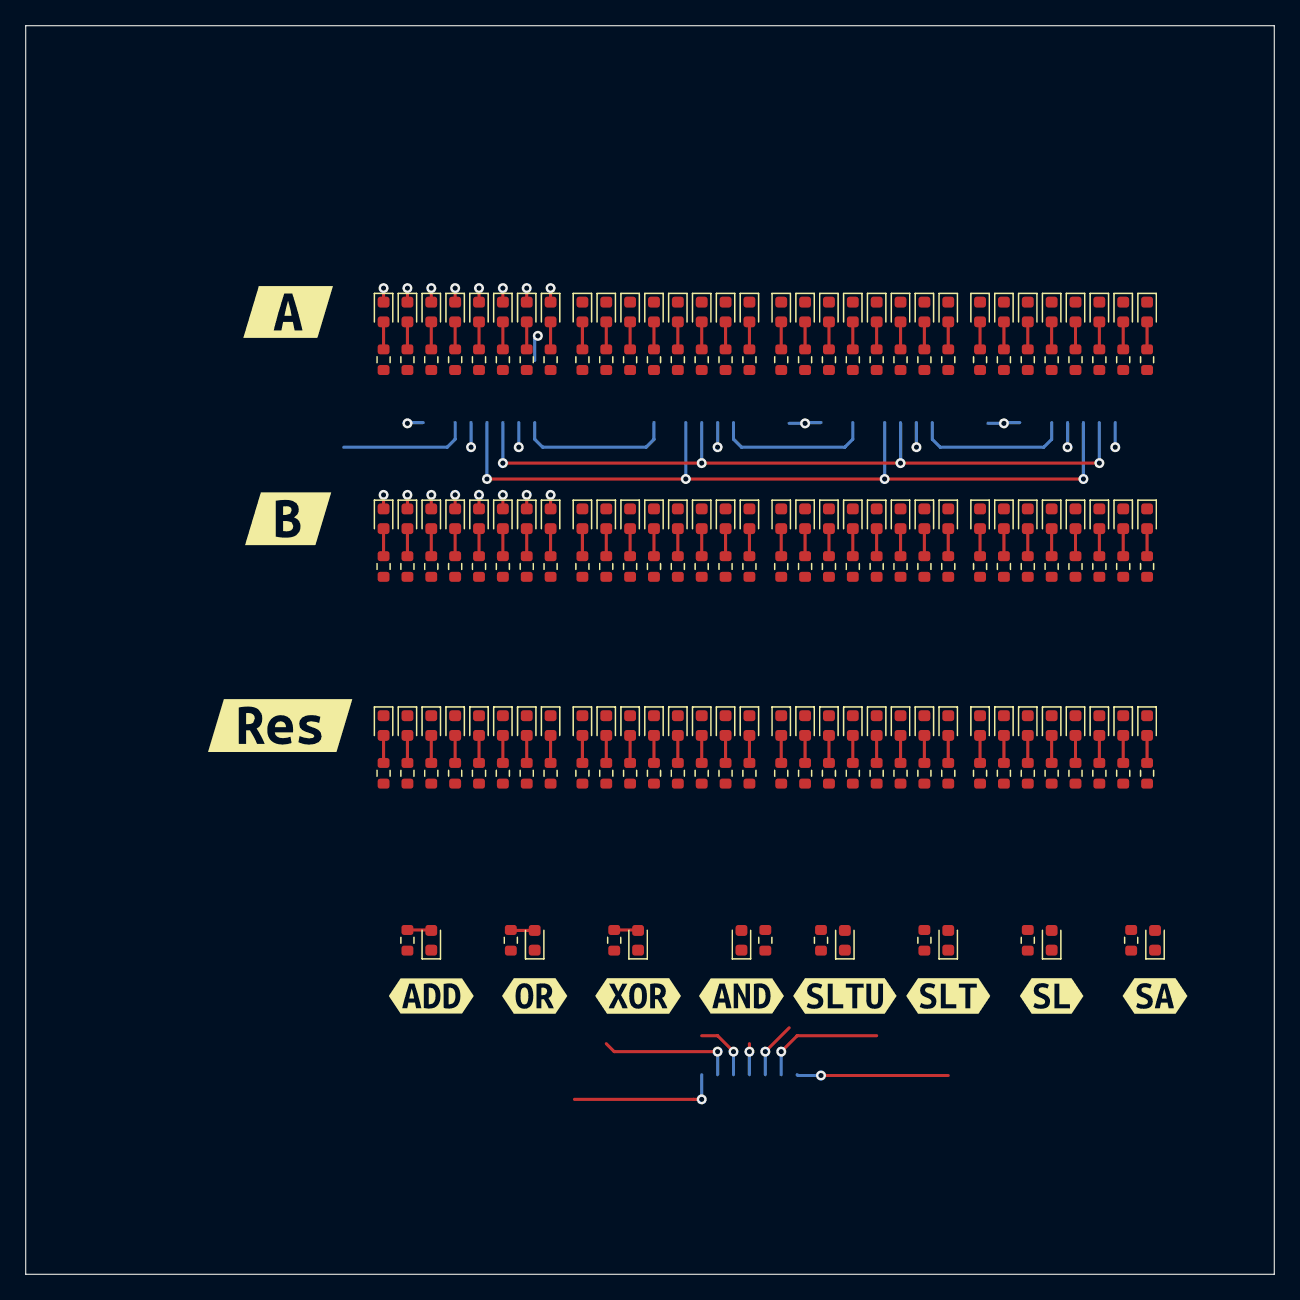
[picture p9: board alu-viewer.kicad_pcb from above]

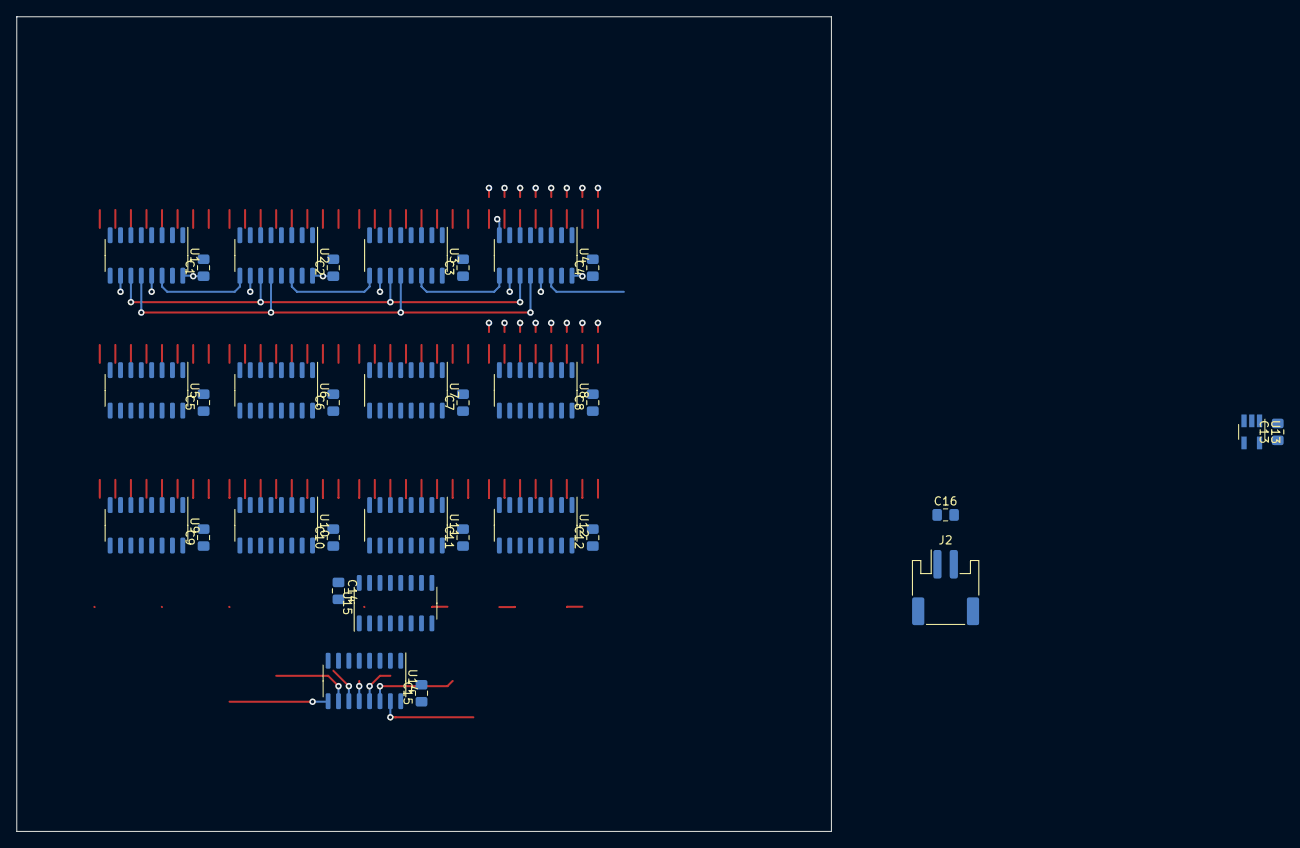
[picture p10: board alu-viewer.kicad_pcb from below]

Board: 4 copper layers, 99.7 x 99.7 mm, 251 parts (32 on the bottom side), 224 nets.

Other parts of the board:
kibuzzard-631087D5: G***; kibuzzard-631087D5
kibuzzard-631087E9: G***; kibuzzard-631087E9
kibuzzard-631088E6: G***; kibuzzard-631088E6
kibuzzard-631088FC: G***; kibuzzard-631088FC
kibuzzard-631089CA: G***; kibuzzard-631089CA
kibuzzard-6310893A: G***; kibuzzard-6310893A
kibuzzard-6310894E: G***; kibuzzard-6310894E
kibuzzard-6310895A: G***; kibuzzard-6310895A
kibuzzard-63108921: G***; kibuzzard-63108921
kibuzzard-63108965: G***; kibuzzard-63108965
kibuzzard-63108972: G***; kibuzzard-63108972

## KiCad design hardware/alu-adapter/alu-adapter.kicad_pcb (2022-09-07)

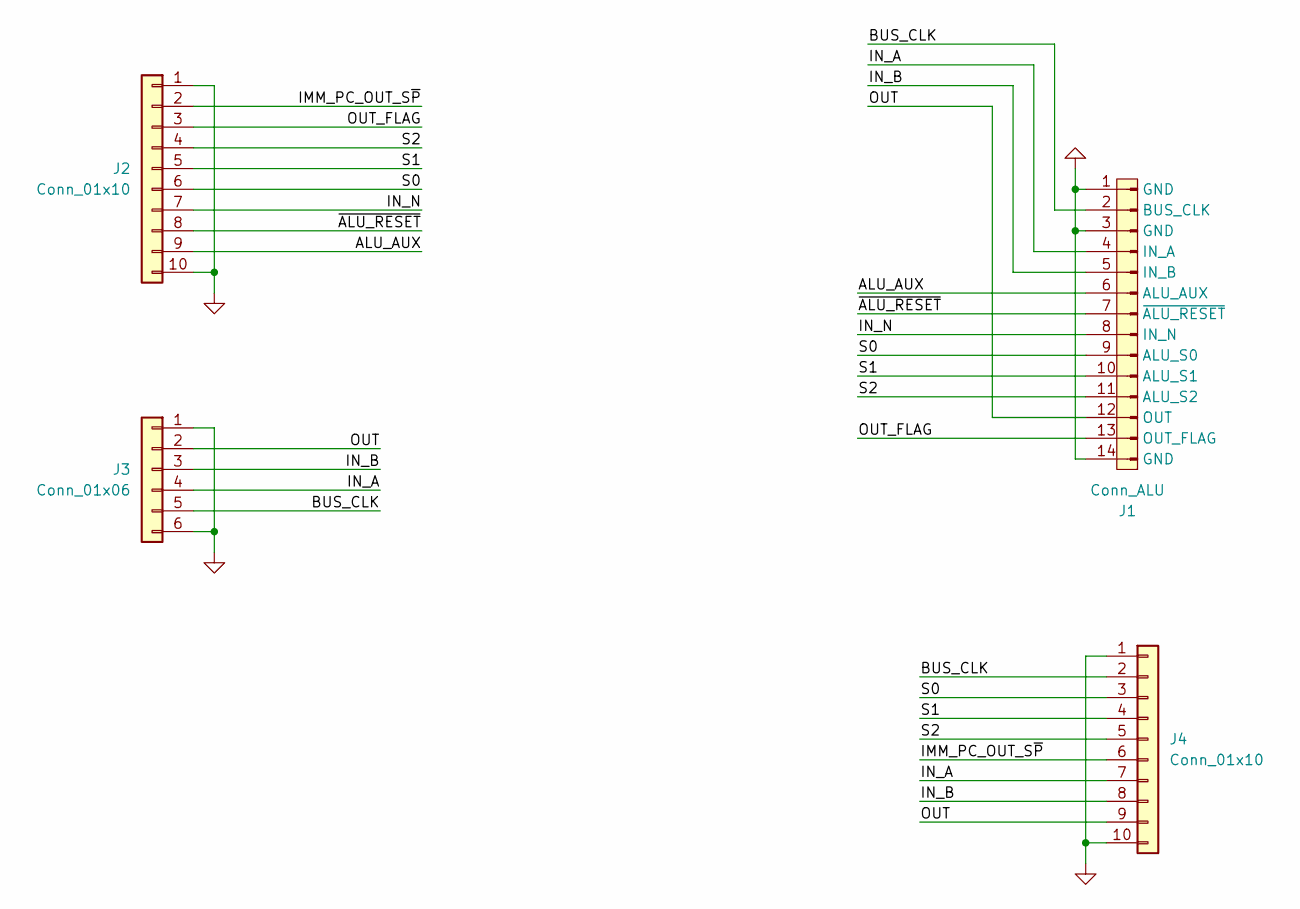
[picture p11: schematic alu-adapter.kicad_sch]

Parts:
J1: Conn_ALU; IDC-Header_2x07_P2.54mm_Vertical
J2, J4: Conn_01x10; IDC-Header_2x05_P2.54mm_Vertical
J3: Conn_01x06; IDC-Header_2x03_P2.54mm_Vertical

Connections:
/ALU_AUX: J1.6 (ALU_AUX), J2.9
/BUS_CLK: J1.2 (BUS_CLK), J3.5, J4.2
/IMM_PC_OUT_S~P: J2.2, J4.6
/IN_A: J1.4 (IN_A), J3.4, J4.7
/IN_B: J1.5 (IN_B), J3.3, J4.8
/IN_N: J1.8 (IN_N), J2.7
/OUT: J1.12 (OUT), J3.2, J4.9
/OUT_FLAG: J1.13 (OUT_FLAG), J2.3
/S0: J1.9 (ALU_S0), J2.6, J4.3
/S1: J1.10 (ALU_S1), J2.5, J4.4
/S2: J1.11 (ALU_S2), J2.4, J4.5
/~ALU_RESET: J1.7 (~ALU_RESET), J2.8
GND: J1.1 (GND), J1.3 (GND), J1.14 (GND), J2.1, J2.10, J3.1, J3.6, J4.1, J4.10

Board: 2 copper layers, 4 parts (0 on the bottom side), 13 nets, no tracks yet.

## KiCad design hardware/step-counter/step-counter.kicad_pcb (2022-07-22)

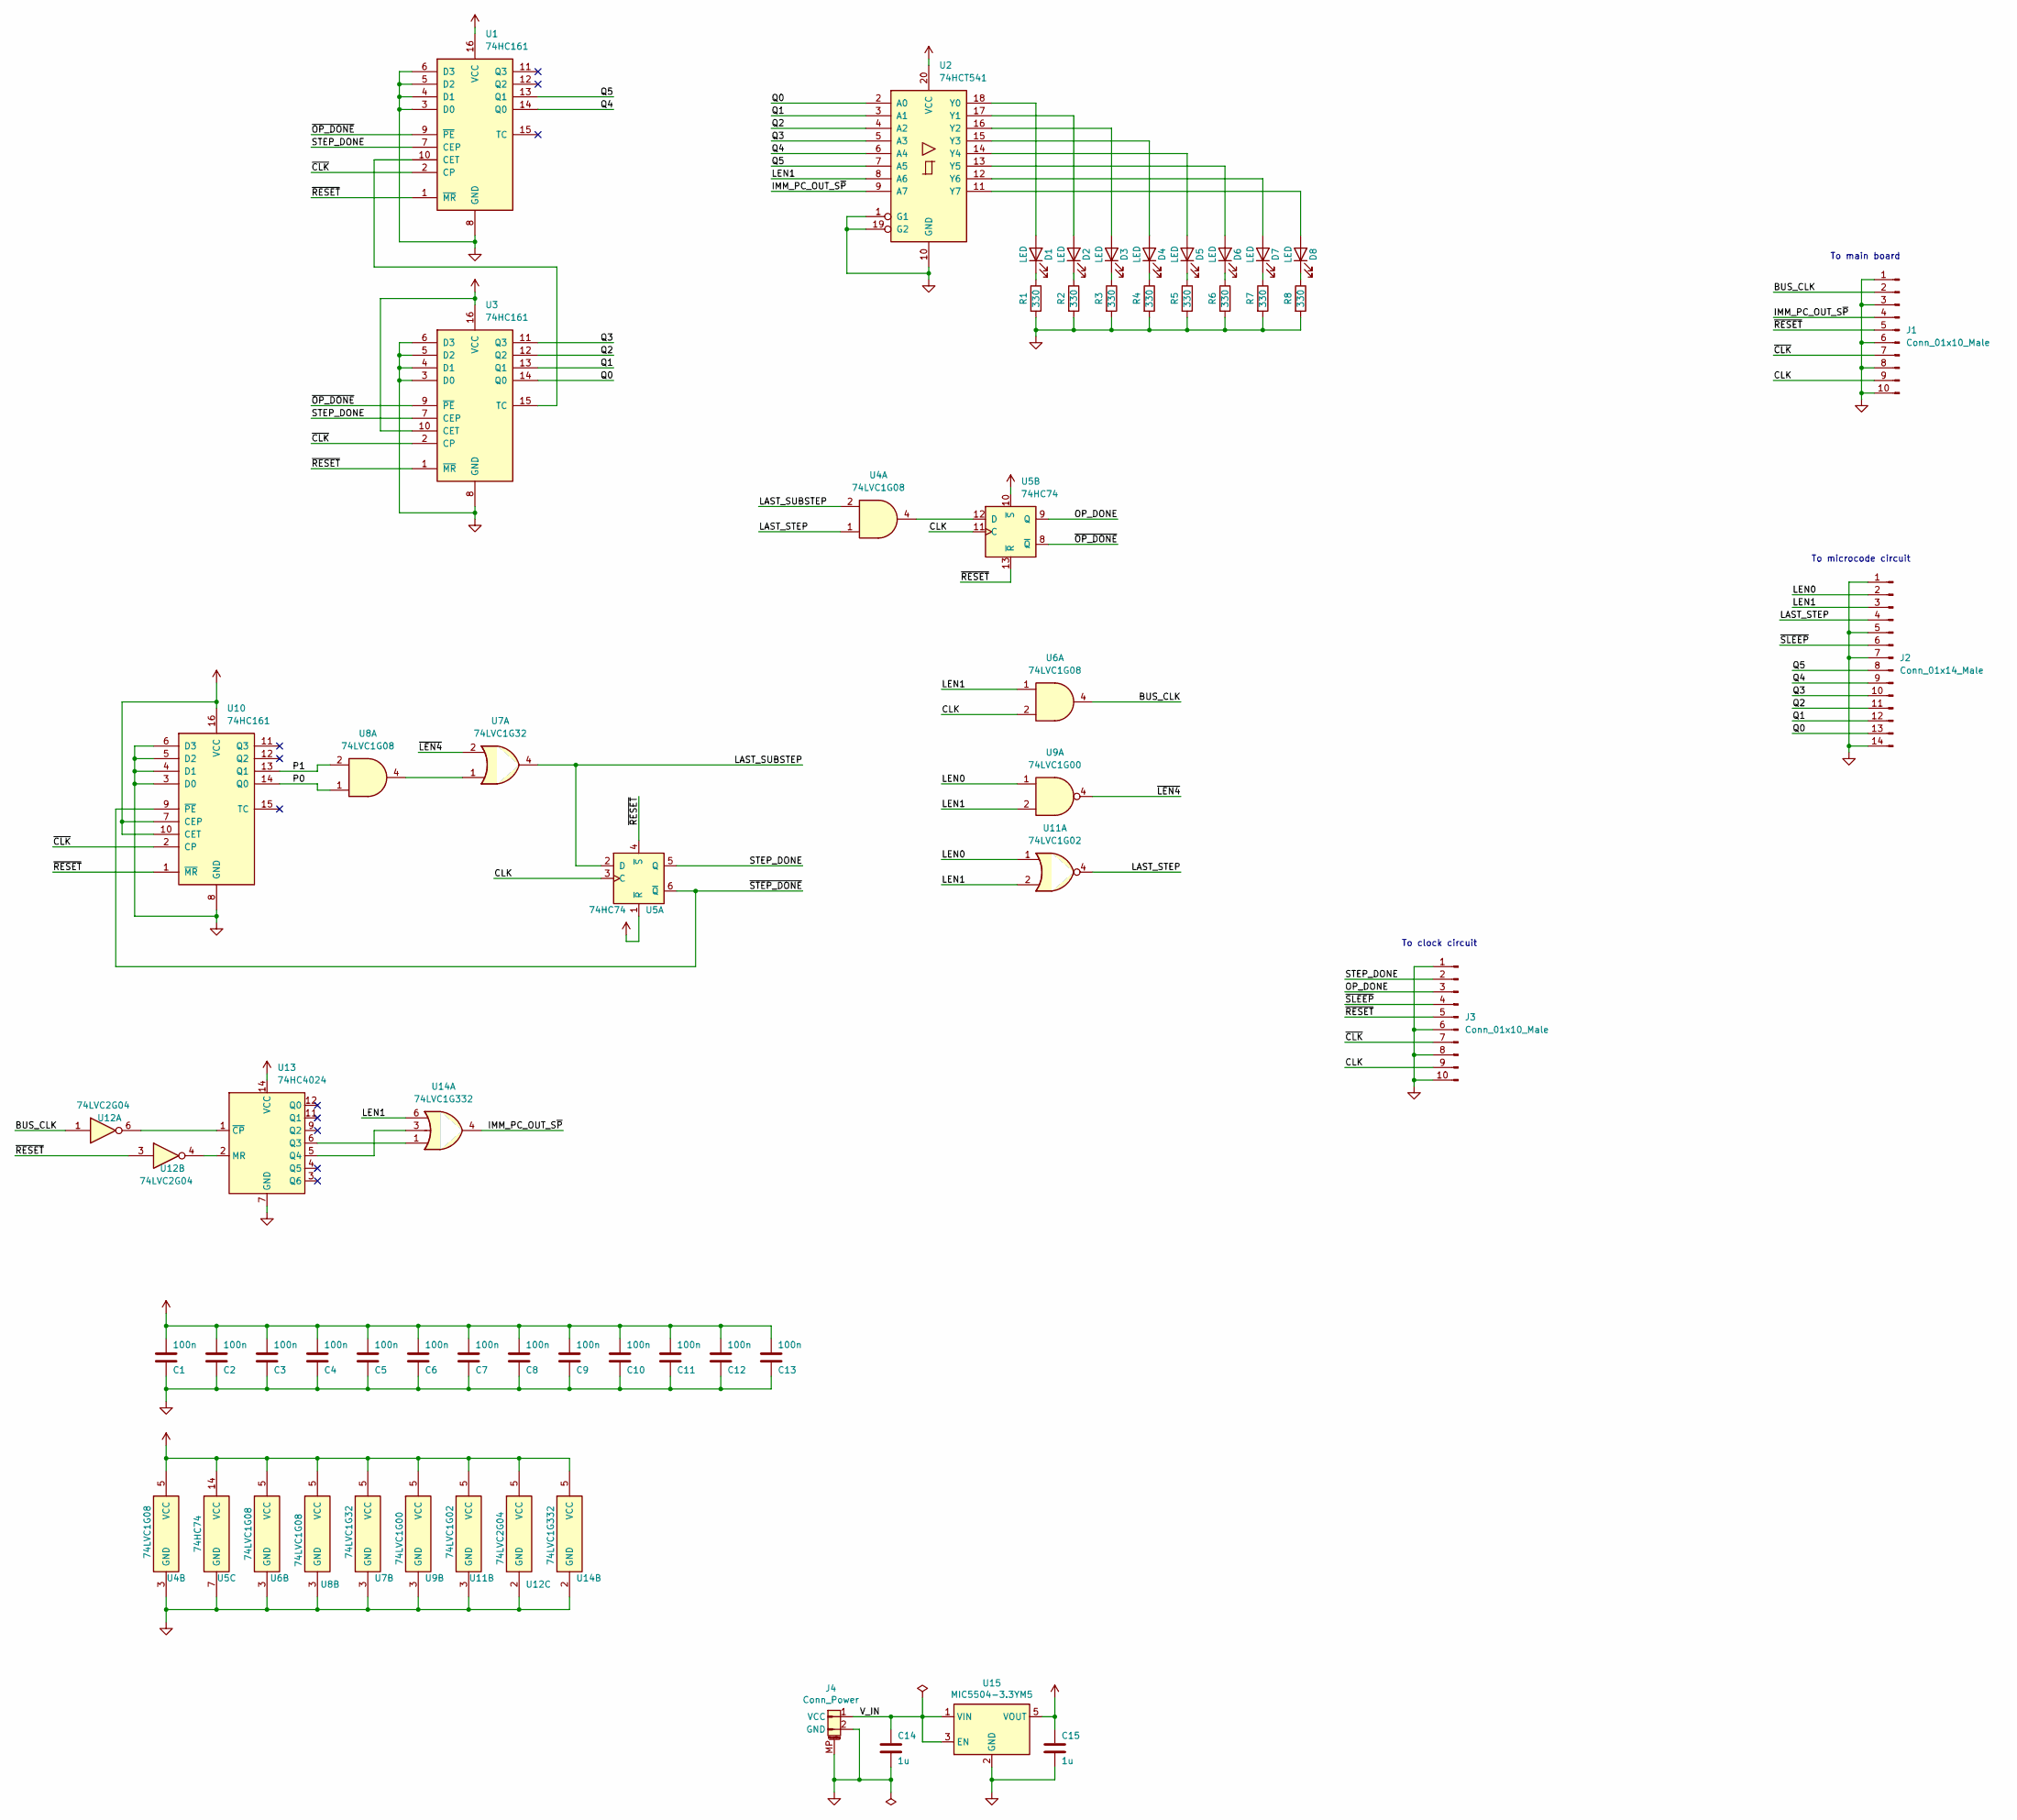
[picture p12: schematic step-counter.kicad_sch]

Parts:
C1, C2, C3, C4, C5, C6, C7, C8, C9, C10, C11, C12, C13: 100n; C_0805_2012Metric_Pad1.18x1.45mm_HandSolder
C14, C15: 1u; C_0805_2012Metric_Pad1.18x1.45mm_HandSolder
D1, D2, D3, D4, D5, D6, D7, D8: LED; LED_0805_2012Metric_Pad1.15x1.40mm_HandSolder
J1, J3: Conn_01x10_Male; IDC-Header_2x05_P2.54mm_Vertical
J2: Conn_01x14_Male; IDC-Header_2x07_P2.54mm_Vertical
J4: Conn_Power; JST_PH_S2B-PH-SM4-TB_1x02-1MP_P2.00mm_Horizontal
R1, R2, R3, R4, R5, R6, R7, R8: 330; R_0805_2012Metric_Pad1.20x1.40mm_HandSolder
U1, U3, U10: 74HC161; SOIC-16_3.9x9.9mm_P1.27mm
U2: 74HCT541; TSSOP-20_4.4x6.5mm_P0.65mm
U4, U6, U8: 74LVC1G08; SOT-23-5_HandSoldering
U5: 74HC74; SOIC-14_3.9x8.7mm_P1.27mm
U7: 74LVC1G32; SOT-23-5_HandSoldering
U9: 74LVC1G00; SOT-23-5_HandSoldering
U11: 74LVC1G02; SOT-23-5_HandSoldering
U12: 74LVC2G04; SOT-23-6_Handsoldering
U13: 74HC4024; SOIC-14_3.9x8.7mm_P1.27mm
U14: 74LVC1G332; SOT-23-6_Handsoldering
U15: MIC5504-3.3YM5; SOT-23-5

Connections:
/BUS_CLK: J1.2, U6.4, U12.1
/CLK: J1.9, J3.9, U5.3 (C), U5.11 (C), U6.2
/IMM_PC_OUT_S~P: J1.4, U2.9 (A7), U14.4
/LAST_STEP: J2.4, U4.1, U11.4
/LAST_SUBSTEP: U4.2, U5.2 (D), U7.4
/LEN0: J2.2, U9.1, U11.1
/LEN1: J2.3, U2.8 (A6), U6.1, U9.2, U11.2, U14.6
/OP_DONE: J3.3, U5.9 (Q)
/P0: U8.1, U10.14 (Q0)
/P1: U8.2, U10.13 (Q1)
/Q0: J2.13, U2.2 (A0), U3.14 (Q0)
/Q1: J2.12, U2.3 (A1), U3.13 (Q1)
/Q2: J2.11, U2.4 (A2), U3.12 (Q2)
/Q3: J2.10, U2.5 (A3), U3.11 (Q3)
/Q4: J2.9, U1.14 (Q0), U2.6 (A4)
/Q5: J2.8, U1.13 (Q1), U2.7 (A5)
/STEP_DONE: J3.2, U1.7 (CEP), U3.7 (CEP), U5.5 (Q)
/V_IN: C14.1, J4.1 (VCC), U15.1 (VIN), U15.3 (EN)
/~CLK: J1.7, J3.7, U1.2 (CP), U3.2 (CP), U10.2 (CP)
/~LEN4: U7.2, U9.4
/~OP_DONE: U1.9 (~PE), U3.9 (~PE), U5.8 (~Q)
/~RESET: J1.5, J3.5, U1.1 (~MR), U3.1 (~MR), U5.4 (~S), U5.13 (~R), U10.1 (~MR), U12.3
/~SLEEP: J2.6, J3.4
/~STEP_DONE: U5.6 (~Q), U10.9 (~PE)
GND: C1.2, C2.2, C3.2, C4.2, C5.2, C6.2, C7.2, C8.2, C9.2, C10.2, C11.2, C12.2, C13.2, C14.2, C15.2, J1.1, J1.3, J1.6, J1.8, J1.10, J2.1, J2.5, J2.7, J2.14, J3.1, J3.6, J3.8, J3.10, J4.2 (GND), J4.MP, R1.2, R2.2, R3.2, R4.2, R5.2, R6.2, R7.2, R8.2, U1.3 (D0), U1.4 (D1), U1.5 (D2), U1.6 (D3), U1.8 (GND), U2.1 (G1), U2.10 (GND), U2.19 (G2), U3.3 (D0), U3.4 (D1), U3.5 (D2), U3.6 (D3), U3.8 (GND), U4.3 (GND), U5.7 (GND), U6.3 (GND), U7.3 (GND), U8.3 (GND), U9.3 (GND), U10.3 (D0), U10.4 (D1), U10.5 (D2), U10.6 (D3), U10.8 (GND), U11.3 (GND), U12.2 (GND), U13.7 (GND), U14.2 (GND), U15.2 (GND)
unnamed: D1.1 (K), R1.1
unnamed: D1.2 (A), U2.18 (Y0)
unnamed: D2.1 (K), R2.1
unnamed: D2.2 (A), U2.17 (Y1)
unnamed: D3.1 (K), R3.1
unnamed: D3.2 (A), U2.16 (Y2)
unnamed: D4.1 (K), R4.1
unnamed: D4.2 (A), U2.15 (Y3)
unnamed: D5.1 (K), R5.1
unnamed: D5.2 (A), U2.14 (Y4)
unnamed: D6.1 (K), R6.1
unnamed: D6.2 (A), U2.13 (Y5)
unnamed: D7.1 (K), R7.1
unnamed: D7.2 (A), U2.12 (Y6)
unnamed: D8.1 (K), R8.1
unnamed: D8.2 (A), U2.11 (Y7)
unnamed: U1.10 (CET), U3.15 (TC)
unnamed: U4.4, U5.12 (D)
unnamed: U7.1, U8.4
unnamed: U12.4, U13.2 (MR)
unnamed: U12.6, U13.1 (~CP)
unnamed: U13.5 (Q4), U14.3
unnamed: U13.6 (Q3), U14.1
VCC: C1.1, C2.1, C3.1, C4.1, C5.1, C6.1, C7.1, C8.1, C9.1, C10.1, C11.1, C12.1, C13.1, C15.1, U1.16 (VCC), U2.20 (VCC), U3.10 (CET), U3.16 (VCC), U4.5 (VCC), U5.1 (~R), U5.10 (~S), U5.14 (VCC), U6.5 (VCC), U7.5 (VCC), U8.5 (VCC), U9.5 (VCC), U10.7 (CEP), U10.10 (CET), U10.16 (VCC), U11.5 (VCC), U12.5 (VCC), U13.14 (VCC), U14.5 (VCC), U15.5 (VOUT)

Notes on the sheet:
To main board
To microcode circuit
To clock circuit

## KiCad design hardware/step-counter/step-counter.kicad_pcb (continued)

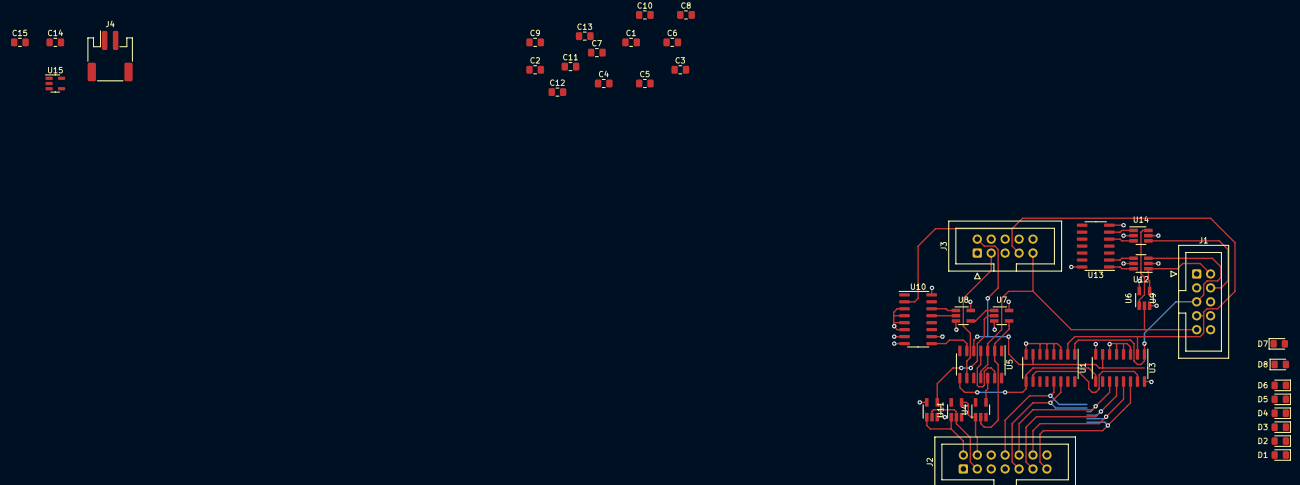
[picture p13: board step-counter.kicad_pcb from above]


Board: 4 copper layers, 50 parts (9 on the bottom side), 49 nets.

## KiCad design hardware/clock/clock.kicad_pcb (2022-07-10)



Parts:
C1, C2, C3, C4, C5, C6, C7, C8, C9, C10, C11, C12, C13, C14, C15, C16, C17, C18, C19, C20, C21, C22, C23, C24, C25, C26, C27, C28, C29, C30, C44, C45: 100n; C_0805_2012Metric_Pad1.18x1.45mm_HandSolder
C31, C32, C33, C34, C35, C36, C40, C41, C42, C43: 1u; C_0805_2012Metric_Pad1.18x1.45mm_HandSolder
C37: 2u2; C_0805_2012Metric_Pad1.18x1.45mm_HandSolder
C38, C39: 32p; C_0805_2012Metric_Pad1.18x1.45mm_HandSolder
D1: 150141RV73100; Wurth WL-SBTW
D2, D3, D4, D5: LED; LED_0805_2012Metric_Pad1.15x1.40mm_HandSolder
J1: Conn_Power; JST_PH_S2B-PH-SM4-TB_1x02-1MP_P2.00mm_Horizontal
J2: Conn_01x03; PinHeader_1x03_P2.54mm_Vertical
J3, J4: Conn_01x02_Male; PinHeader_1x02_P2.54mm_Vertical
J5: Conn_01x10_Male; IDC-Header_2x05_P2.54mm_Vertical
R1, R2, R3, R4, R5, R6, R7, R8, R9, R12, R13, R14, R15, R16, R17, R23, R26: 33k; R_0805_2012Metric_Pad1.20x1.40mm_HandSolder
R10, R11: 220; R_0805_2012Metric_Pad1.20x1.40mm_HandSolder
R18, R25: 100k; R_0805_2012Metric_Pad1.20x1.40mm_HandSolder
R19, R21: 1k; R_0805_2012Metric_Pad1.20x1.40mm_HandSolder
R20: 2M2; R_0805_2012Metric_Pad1.20x1.40mm_HandSolder
R22: 10k; R_0805_2012Metric_Pad1.20x1.40mm_HandSolder
R24: 0; Jumper_3_R_0805
R27, R28, R29, R30: 330; R_0805_2012Metric_Pad1.20x1.40mm_HandSolder
RV1: R_Potentiometer; Potentiometer_Bourns_PTV09A-1_Single_Vertical
SW1, SW2, SW3, SW4, SW5, SW6, SW7, SW8: SW_Push_4pin; SW_SPST_DTSM-6
U1, U8, U27, U29: 74HC74; SOIC-14_3.9x8.7mm_P1.27mm
U2, U4, U9: 74HCS05; SOIC-14_3.9x8.7mm_P1.27mm
U3, U28: 74LVC1G02; SOT-23-5_HandSoldering
U5, U10, U13: 74LVC1G38; SOT-23-5_HandSoldering
U6: 74LVC2G74; TSSOP-8_3x3mm_P0.65mm
U7: 74LVC1G08; SOT-23-5_HandSoldering
U11: 74LVC1G00; SOT-23-5_HandSoldering
U12: 74HC00; SOIC-14_3.9x8.7mm_P1.27mm
U14: 74HC02; SOIC-14_3.9x8.7mm_P1.27mm
U15: 74LVC1G14; SOT-23-5_HandSoldering
U16, U17: 74HC4017; SOIC-16_3.9x9.9mm_P1.27mm
U18: 74LVC2G04; SOT-23-6_Handsoldering
U19: 74LVC1GX04; SOT-23-6_Handsoldering
U20, U23, U30, U32, U33: 74LVC1G04; SOT-23-5_HandSoldering
U21: NE555D; SOIC-8_3.9x4.9mm_P1.27mm
U22: 74LVC1G32; SOT-23-5_HandSoldering
U24: MIC5504-3.3YM5; SOT-23-5
U25: 74HC08; SOIC-14_3.9x8.7mm_P1.27mm
U26, U31: 74LVC1G132; SOT-23-5_HandSoldering
Y1: Crystal; Crystal_HC49-U_Vertical

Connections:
/B_555: R25.2, R26.2, SW8.1, SW8.2
/B_INSTR: C32.1, R8.1, U1.3 (C), U2.5
/B_OSC: R22.2, R23.2, SW7.1, SW7.2
/B_RESET: R19.2, SW6.3, SW6.4
/B_RUN: C31.1, R6.1, U1.11 (C)
/B_STEP: C33.1, R12.1, U2.9, U4.9, U8.11 (C)
/B_STOP: C35.1, R16.1, U2.3, U4.3, U9.3, U9.11
/B_SUBSTEP: C34.1, R14.1, U2.11, U4.5, U8.3 (C), U9.5
/CLK: J5.9, U14.5, U14.10, U18.1
/CLK_555: U21.3 (Q), U25.13, U29.11 (C), U30.2
/CLK_OSC: U19.6 (Y), U23.2, U25.5, U27.3 (C)
/GREEN: D1.2 (A2), U11.2, U12.9, U12.11
/LED_555: D5.1 (K), R30.1
/LED_G_K: D1.4 (K2), R10.2
/LED_OSC: D4.1 (K), R29.1
/LED_R_K: D1.3 (K1), R11.2
/OP_DONE: J5.3, U5.1
/Q0: U12.2, U12.5, U14.11, U17.3 (Q0)
/Q3: U6.1 (C), U17.7 (Q3)
/Q4: U14.3, U17.10 (Q4)
/Q5: U5.2, U10.2, U13.1, U13.2, U14.6, U17.1 (Q5)
/Q9: U17.11 (Q9), U22.1
/RAW_CLK: R24.2, U16.14 (CP0), U17.14 (CP0)
/RESET: U2.1, U3.2, U4.1, U9.1, U9.13, U17.15 (MR), U20.4, U22.2
/STEP_DONE: J5.2, U10.1
/V_IN: C40.1, J1.1 (VCC), U24.1 (VIN), U24.3 (EN)
/WAKEUP: J3.1, U3.1
/~CLK_EN: D1.1 (A1), U11.4, U17.13 (~CP1)
/~CLK: J5.7, U14.1, U14.12, U18.3
/~RESET: J5.5, U16.11 (Q9), U16.13 (~CP1), U20.2
/~R_INSTR: R3.2, U1.1 (~R), U4.2, U4.4, U4.6, U4.8, U5.4
/~R_RUN: R4.2, U1.13 (~R), U2.2, U2.4, U2.6, U2.8, U2.10
/~R_STEP: R2.2, U8.13 (~R), U9.2, U9.4, U9.6, U10.4
/~R_SUBSTEP: R1.2, U8.1 (~R), U9.10, U9.12, U13.4
/~SLEEP: J5.4, U6.2 (D)
/~WAIT: J4.1, U7.2
GND: C1.2, C2.2, C3.2, C4.2, C5.2, C6.2, C7.2, C8.2, C9.2, C10.2, C11.2, C12.2, C13.2, C14.2, C15.2, C16.2, C17.2, C18.2, C19.2, C20.2, C21.2, C22.2, C23.2, C24.2, C25.2, C26.2, C27.2, C28.2, C29.2, C30.2, C31.2, C32.2, C33.2, C34.2, C35.2, C36.2, C37.2, C38.2, C39.2, C40.2, C41.2, C42.2, C43.2, C44.2, C45.2, J1.2 (GND), J1.MP, J2.3, J3.2, J4.2, J5.1, J5.6, J5.8, J5.10, R7.2, R9.2, R10.1, R11.1, R13.2, R15.2, R17.2, SW6.1, SW6.2, SW7.3, SW7.4, SW8.3, SW8.4, U1.7 (GND), U2.7 (GND), U3.3 (GND), U4.7 (GND), U5.3 (GND), U6.4 (GND), U7.3 (GND), U8.7 (GND), U9.7 (GND), U10.3 (GND), U11.3 (GND), U12.7 (GND), U13.3 (GND), U14.7 (GND), U15.3 (GND), U16.8 (GND), U17.8 (GND), U18.2 (GND), U19.2 (GND), U20.3 (GND), U21.1 (GND), U22.3 (GND), U23.3 (GND), U24.2 (GND), U25.7 (GND), U26.3 (GND), U27.7 (GND), U28.3 (GND), U29.7 (GND), U30.3 (GND), U31.3 (GND), U32.3 (GND), U33.3 (GND)
unnamed: C36.1, R18.1, R19.1, U15.2
unnamed: C37.1, RV1.3, U21.2 (TR), U21.6 (THR)
unnamed: C38.1, R20.1, U19.3 (X1), Y1.1
unnamed: C39.1, R21.1, Y1.2
unnamed: C42.1, R23.1, U26.1
unnamed: C43.1, R26.1, U31.1
unnamed: D2.1 (K), R27.1
unnamed: D3.1 (K), R28.1
unnamed: J2.2, R24.3
unnamed: R5.2, U2.12, U4.10, U4.12, U9.8, U12.1
unnamed: R6.2, R7.1, SW1.1, SW1.2
unnamed: R8.2, R9.1, SW2.1, SW2.2
unnamed: R12.2, R13.1, SW3.1, SW3.2
unnamed: R14.2, R15.1, SW4.1, SW4.2
unnamed: R16.2, R17.1, SW5.1, SW5.2
unnamed: R20.2, R21.2, U19.4 (X2)
unnamed: R24.1, U28.4
unnamed: R27.2, U18.4
unnamed: R28.2, U18.6
unnamed: R29.2, U32.4
unnamed: R30.2, U33.4
unnamed: U1.6 (~Q), U4.11
unnamed: U1.8 (~Q), U2.13
unnamed: U3.4, U6.7 (~S)
unnamed: U4.13, U8.6 (~Q)
unnamed: U6.5 (Q), U7.1
unnamed: U8.8 (~Q), U9.9
unnamed: U7.4, U11.1
unnamed: U12.6, U12.10
unnamed: U12.3, U12.4, U12.12
unnamed: U12.8, U12.13
unnamed: U14.4, U14.8
unnamed: U14.9, U22.4
unnamed: U14.2, U14.13
unnamed: U15.4, U16.15 (MR)
unnamed: U23.4, U27.11 (C)
unnamed: U25.1, U27.8 (~Q)
unnamed: U25.2, U26.2, U31.4
unnamed: U25.3, U29.12 (D)
unnamed: U25.4, U27.9 (Q), U32.2
unnamed: U25.6, U28.2
unnamed: U25.8, U27.2 (D)
unnamed: U25.9, U26.4, U31.2
unnamed: U25.10, U29.6 (~Q)
unnamed: U25.11, U28.1
unnamed: U25.12, U29.5 (Q), U33.2
unnamed: U27.5 (Q), U27.12 (D)
unnamed: U29.2 (D), U29.9 (Q)
unnamed: U29.3 (C), U30.4
VCC: C1.1, C2.1, C3.1, C4.1, C5.1, C6.1, C7.1, C8.1, C9.1, C10.1, C11.1, C12.1, C13.1, C14.1, C15.1, C16.1, C17.1, C18.1, C19.1, C20.1, C21.1, C22.1, C23.1, C24.1, C25.1, C26.1, C27.1, C28.1, C29.1, C30.1, C41.1, C44.1, C45.1, D2.2 (A), D3.2 (A), D4.2 (A), D5.2 (A), J2.1, R1.1, R2.1, R3.1, R4.1, R5.1, R18.2, R22.1, R25.1, RV1.1, RV1.2, SW1.3, SW1.4, SW2.3, SW2.4, SW3.3, SW3.4, SW4.3, SW4.4, SW5.3, SW5.4, U1.2 (D), U1.4 (~S), U1.10 (~S), U1.12 (D), U1.14 (VCC), U2.14 (VCC), U3.5 (VCC), U4.14 (VCC), U5.5 (VCC), U6.6 (~R), U6.8 (VCC), U7.5 (VCC), U8.2 (D), U8.4 (~S), U8.10 (~S), U8.12 (D), U8.14 (VCC), U9.14 (VCC), U10.5 (VCC), U11.5 (VCC), U12.14 (VCC), U13.5 (VCC), U14.14 (VCC), U15.5 (VCC), U16.16 (VCC), U17.16 (VCC), U18.5 (VCC), U19.5 (VCC), U20.5 (VCC), U21.4 (R), U21.7 (DIS), U21.8 (VCC), U22.5 (VCC), U23.5 (VCC), U24.5 (VOUT), U25.14 (VCC), U26.5 (VCC), U27.1 (~R), U27.4 (~S), U27.10 (~S), U27.13 (~R), U27.14 (VCC), U28.5 (VCC), U29.1 (~R), U29.4 (~S), U29.10 (~S), U29.13 (~R), U29.14 (VCC), U30.5 (VCC), U31.5 (VCC), U32.5 (VCC), U33.5 (VCC)

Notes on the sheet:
Vf(10mA) = 2V
RC=0.1s
RC = 33ms
Replace with 74LVC1G373?



Board: 4 copper layers, 99.1 x 99.1 mm, 128 parts (40 on the bottom side), 87 nets.

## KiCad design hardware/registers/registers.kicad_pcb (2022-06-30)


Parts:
C1, C2, C3, C4, C5, C6, C9, C10: 100n; C_0805_2012Metric_Pad1.18x1.45mm_HandSolder
C7, C8: 1u; C_0805_2012Metric_Pad1.18x1.45mm_HandSolder
D1, D2, D3, D4, D5, D6: LED; LED_0805_2012Metric_Pad1.15x1.40mm_HandSolder
J1, J2: Conn_Reg; IDC-Header_2x10_P2.54mm_Vertical
J3: Conn_Reg_Sel; IDC-Header_2x10_P2.54mm_Vertical
J4: Conn_Power; JST_PH_S2B-PH-SM4-TB_1x02-1MP_P2.00mm_Horizontal
J5, J6: Conn_Reg_Data; IDC-Header_2x05_P2.54mm_Vertical
R1, R2, R3, R4, R5, R6: 390; R_0805_2012Metric_Pad1.20x1.40mm_HandSolder
R7, R8: 0; R_0805_2012Metric_Pad1.20x1.40mm_HandSolder
U1, U2, U3: 74LVC1G19; SOT-23-6_Handsoldering
U4, U5, U6: 74LVC1G86; SOT-23-5_HandSoldering
U7: MIC5504-3.3YM5; SOT-23-5_HandSoldering
U8: 74LVC1G32; SOT-23-5_HandSoldering
U9: 74LVC1G04; SOT-23-5_HandSoldering

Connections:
/BANK: R7.1, R8.2, U4.2, U5.2, U6.2
/BUS_CLK: J1.2 (BUS_CLK), J2.2 (BUS_CLK), J5.9 (BUS_CLK), J6.9 (BUS_CLK)
/RAOUT: J1.5 (RAOUT), J2.5 (RAOUT), J5.6 (RAOUT), J6.6 (RAOUT)
/RAS0: J1.17 (RAS0), J2.17 (RAS0), J3.15 (RAS0)
/RAS1: J1.18 (RAS1), J2.18 (RAS1), J3.16 (RAS1)
/RAS2: J1.19 (RAS2), J2.19 (RAS2), J3.17 (RAS2)
/RAS3: J3.18 (RAS3), U1.1 (S)
/RAS4: J3.19 (RAS4), U4.1
/RBOUT: J1.6 (RBOUT), J2.6 (RBOUT), J5.5 (RBOUT), J6.5 (RBOUT)
/RBS0: J1.14 (RBS0), J2.14 (RBS0), J3.9 (RBS0)
/RBS1: J1.15 (RBS1), J2.15 (RBS1), J3.10 (RBS1)
/RBS2: J1.16 (RBS2), J2.16 (RBS2), J3.11 (RBS2)
/RBS3: J3.12 (RBS3), U2.1 (S)
/RBS4: J3.13 (RBS4), U5.1
/RESET: J1.7 (RESET), J2.7 (RESET), U9.4
/RIN: J1.4 (RIN), J2.4 (RIN), J5.7 (RIN), J6.7 (RIN)
/RINS0: J1.11 (RINS0), J2.11 (RINS0), J3.3 (RINS0)
/RINS1: J1.12 (RINS1), J2.12 (RINS1), J3.4 (RINS1)
/RINS2: J1.13 (RINS2), J2.13 (RINS2), J3.5 (RINS2)
/RINS3: J3.6 (RINS3), U3.1 (S)
/RINS4: J3.7 (RINS4), U6.1
/V_IN: C7.1, J4.1 (VCC), U7.1 (VIN), U7.3 (EN)
/~IN_EN': U3.3 (I), U8.4
/~IN_EN_0: D3.1 (K), J1.8 (~RIN_EN), U3.6 (Y0)
/~IN_EN_1: J2.8 (~RIN_EN), R6.1, U3.4 (Y1)
/~IN_EN: J5.2 (~IN_EN), J6.2 (~IN_EN), U8.2
/~OUT_A_EN_0: D1.1 (K), J1.10 (~ROUT_EN_B), U1.6 (Y0)
/~OUT_A_EN_1: J2.10 (~ROUT_EN_B), R4.1, U1.4 (Y1)
/~OUT_A_EN: U1.3 (I), U4.4
/~OUT_B_EN_0: D2.1 (K), J1.9 (~ROUT_EN_A), U2.6 (Y0)
/~OUT_B_EN_1: J2.9 (~ROUT_EN_A), R5.1, U2.4 (Y1)
/~OUT_B_EN: U2.3 (I), U5.4
/~RESET: J5.4 (~RESET), J6.4 (~RESET), U9.2
GND: C1.2, C2.2, C3.2, C4.2, C5.2, C6.2, C7.2, C8.2, C9.2, C10.2, J1.1 (GND), J1.3 (GND), J1.20 (GND), J2.1 (GND), J2.3 (GND), J2.20 (GND), J3.1 (GND), J3.2 (GND), J3.8 (GND), J3.14 (GND), J3.20 (GND), J4.2 (GND), J4.MP, J5.1 (GND), J5.3 (GND), J5.8 (GND), J5.10 (GND), J6.1 (GND), J6.3 (GND), J6.8 (GND), J6.10 (GND), R8.1, U1.2 (GND), U2.2 (GND), U3.2 (GND), U4.3 (GND), U5.3 (GND), U6.3 (GND), U7.2 (GND), U8.3 (GND), U9.3 (GND)
unnamed: D1.2 (A), R1.1
unnamed: D2.2 (A), R2.1
unnamed: D3.2 (A), R3.1
unnamed: D4.1 (K), R4.2
unnamed: D5.1 (K), R5.2
unnamed: D6.1 (K), R6.2
unnamed: U6.4, U8.1
VCC: C1.1, C2.1, C3.1, C4.1, C5.1, C6.1, C8.1, C9.1, C10.1, D4.2 (A), D5.2 (A), D6.2 (A), R1.2, R2.2, R3.2, R7.2, U1.5 (VCC), U2.5 (VCC), U3.5 (VCC), U4.5 (VCC), U5.5 (VCC), U6.5 (VCC), U7.5 (VOUT), U8.5 (VCC), U9.5 (VCC)



Board: 4 copper layers, 101.6 x 44.4 mm, 39 parts (4 on the bottom side), 42 nets.

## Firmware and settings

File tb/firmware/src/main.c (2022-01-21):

#include "defines.h"
#include "systick.h"
#include "uart.h"

#include "spi.h"
#include "mcp2317.h"
#include "cbuf.h"
#include "pwm.h"

#include "console.h"

#include <unistd.h>
#include <stdio.h>
#include <string.h>

#define CS_GPIO GPIOA
#define CS (1UL << 4)

#define LEDG_GPIO GPIOA
#define LEDG (1UL << 8)

#define LEDR_GPIO GPIOA
#define LEDR (1UL << 9)

#define INT_GPIO GPIOB
#define INT (1UL << 3)

int main(void)
{
    RCC->CR = RCC_CR_HSION;

    RCC->IOPENR = RCC_IOPENR_GPIOAEN | RCC_IOPENR_GPIOBEN;
    RCC->AHBENR = RCC_AHBENR_FLASHEN | RCC_AHBENR_DMA1EN;
    RCC->APBENR1 = RCC_APBENR1_USART2EN;
    RCC->APBENR2 = RCC_APBENR2_SYSCFGEN | RCC_APBENR2_TIM1EN | RCC_APBENR2_SPI1EN;

    FLASH->ACR |= FLASH_ACR_PRFTEN;

    do {
        FLASH->ACR |= FLASH_ACR_LATENCY_2WS;
    } while((FLASH->ACR & FLASH_ACR_LATENCY_Msk) != 2UL);

    while(RCC->CR & RCC_CR_PLLRDY) {}

    RCC->PLLCFGR = RCC_PLLCFGR_PLLR_Val(2) | RCC_PLLCFGR_PLLN_Val(8) | RCC_PLLCFGR_PLLM_Val(1) | RCC_PLLCFGR_PLLSRC_HSI;

    RCC->CR |= RCC_CR_PLLON;

    while(!(RCC->CR & RCC_CR_PLLRDY)) {}

    RCC->PLLCFGR |= RCC_PLLCFGR_PLLREN;

    RCC->CFGR |= RCC_CFGR_SW_PLLRCLK;

    systick_init();

    SYSCFG->CFGR1 = SYSCFG_CFGR1_PA11_RMP;

    GPIOA->AFR[0] =
        GPIOA_AFR0_PA2_UART2_TX  |
        GPIOA_AFR0_PA3_UART2_RX  |
        GPIOA_AFR0_PA5_SPI1_SCK  |
        GPIOA_AFR0_PA6_SPI1_MISO |
        GPIOA_AFR0_PA7_SPI1_MOSI ;

    GPIOA->AFR[1] =
        GPIOA_AFR1_PA8_TIM1_CH1 |
        GPIOA_AFR1_PA9_TIM1_CH2 |
        GPIOA_AFR1_PA13_SWDIO   |
        GPIOA_AFR1_PA14_SWCLK   ;

    GPIOA->OTYPER = 0;
    GPIOA->OSPEEDR =
        (GPIO_OSPEEDR_MID << 2)  | // PA2: UART2_TX
        (GPIO_OSPEEDR_MID << 4)  | // PA4: CS
        (GPIO_OSPEEDR_HI  << 5)  | // PA5: SPI1_SCK
        (GPIO_OSPEEDR_HI  << 7)  | // PA7: SPI1_MOSI
        (GPIO_OSPEEDR_MID << 8)  | // PA8: TIM1_CH1
        (GPIO_OSPEEDR_MID << 9)  | // PA9: TIM1_CH2
        (GPIO_OSPEEDR_VHI << 13) ; // PA13: SWDIO

    GPIOA->PUPDR =
        (GPIO_PUPDR_PU << 26) | // PA13: SWDIO
        (GPIO_PUPDR_PD << 28) ; // PA14: SWCLK

    GPIOA->MODER =
        (GPIO_MODER_ANALOG << 0)  | // PA0: Unused
        (GPIO_MODER_ANALOG << 2)  | // PA1: Unused
        (GPIO_MODER_AF     << 4)  | // PA2: UART2_TX
        (GPIO_MODER_AF     << 6)  | // PA3: UART2_RX
        (GPIO_MODER_OUTPUT << 8)  | // PA4: CS
        (GPIO_MODER_AF     << 10) | // PA5: SPI1_SCK
        (GPIO_MODER_AF     << 12) | // PA6: SPI1_MISO
        (GPIO_MODER_AF     << 14) | // PA7: SPI1_MOSI
        (GPIO_MODER_AF     << 16) | // PA8: TIM1_CH1
        (GPIO_MODER_AF     << 18) | // PA9: TIM1_CH2
        // (GPIO_MODER_OUTPUT    << 18) | // PA9: TIM1_CH2
        (GPIO_MODER_ANALOG << 20) | // PA10: Unused
        (GPIO_MODER_ANALOG << 22) | // PA11: Unused
        (GPIO_MODER_ANALOG << 24) | // PA12: Unused
        (GPIO_MODER_AF     << 26) | // PA13: SWDIO
        (GPIO_MODER_AF     << 28) | // PA14: SWCLK
        (GPIO_MODER_ANALOG << 30) ; // PA15: Unused

    GPIOB->MODER =
        (GPIO_MODER_ANALOG << 0)  |
        (GPIO_MODER_ANALOG << 2)  |
        (GPIO_MODER_ANALOG << 4)  |
        (GPIO_MODER_INPUT  << 6)  | // PB3: INT
        (GPIO_MODER_ANALOG << 8)  |
        (GPIO_MODER_ANALOG << 10) |
        (GPIO_MODER_ANALOG << 12) |
        (GPIO_MODER_ANALOG << 14) |
        (GPIO_MODER_ANALOG << 16) |
        (GPIO_MODER_ANALOG << 18) |
        (GPIO_MODER_ANALOG << 20) |
        (GPIO_MODER_ANALOG << 22) |
        (GPIO_MODER_ANALOG << 24) |
        (GPIO_MODER_ANALOG << 26) |
        (GPIO_MODER_ANALOG << 28) |
        (GPIO_MODER_ANALOG << 30) ;


    GPIOA->BSRR = (LEDR << 16) | (LEDG << 16) | CS;

    pwm_init();

    uart_init();

    // for(;;) {
    //     const char *s = "0123456789abcdef";
    //     write(1, s, strlen(s));
    //     delay(250);
    // }

    // puts("\e[2J\r\nStarting...\r\n");

    delay(100);

    spi_init();
    mcp2317_init();

    // for(int i = 0; i < 5; i++) {
    //     mcp2317_write(i, MCP2317_REG_IOCON, MCP2317_MIRROR | MCP2317_HAEN | MCP2317_ODR);
    // }

    // printf("IOCON:\r\n");
    // for(int i = 0; i < 5; i++) {
    //     uint8_t d = mcp2317_read(i, MCP2317_REG_IOCON);
    //     printf("%d: %02X\r\n", i, d);
    // }

    // printf("IODIRA:\r\n");
    // for(int i = 0; i < 5; i++) {
    //     uint8_t d = mcp2317_read(i, MCP2317_REG_IODIRA);
    //     printf("%d: %02X\r\n", i, d);
    // }

    // printf("IOPOLA:\r\n");
    // for(int i = 0; i < 5; i++) {
    //     uint8_t d = mcp2317_read(i, MCP2317_REG_IPOLA);
    //     printf("%d: %02X\r\n", i, d);
    // }

    // printf("IOCON:\r\n");
    // for(int i = 0; i < 5; i++) {
    //     uint8_t d = mcp2317_read(i, MCP2317_REG_IOCON);
    //     printf("%d: %02X\r\n", i, d);
    // }

    // for(int j = 0; j < 5; j++) {
    //     mcp2317_write(j, MCP2317_REG_IPOLA, 1 << j);
    //     printf("IOPOLA:\r\n");
    //     for(int i = 0; i < 5; i++) {
    //         uint8_t d = mcp2317_read(i, MCP2317_REG_IPOLA);
    //         printf("%d: %02X\r\n", i, d);
    //     }

    // }

    // for(int j = 0; j < 5; j++) {
    //     mcp2317_write(j, MCP2317_REG_IPOLA, 0);
    // }

    // printf("IOPOLA:\r\n");
    // for(int i = 0; i < 5; i++) {
    //     uint8_t d = mcp2317_read(i, MCP2317_REG_IPOLA);
    //     printf("%d: %02X\r\n", i, d);
    // }

    // // mcp2317_write(1, MCP2317_REG_GPPUA, 0x55);

    // printf("GPIO:\r\n");
    // for(int i = 0; i < 5; i++) {
    //     uint8_t d1 = mcp2317_read(i, MCP2317_REG_GPIOA);
    //     uint8_t d2 = mcp2317_read(i, MCP2317_REG_GPIOB);
    //     printf("%d: %02X %02X\r\n", i, d1, d2);
    // }

    // mcp2317_write(0, MCP2317_REG_IODIRB, (uint8_t)~0xC0);
    // mcp2317_write(1, MCP2317_REG_IODIRA, (uint8_t)~0xFF);
    // mcp2317_write(1, MCP2317_REG_IODIRB, (uint8_t)~0xFF);

    // for(uint32_t j = 0 ;; j++) {
    //     printf("%04lx\r\n", j);
    //     delay(500);

    //     mcp2317_write(0, MCP2317_REG_OLATB, 0x80);
    //     mcp2317_write(1, MCP2317_REG_OLATA, 0x55);
    //     mcp2317_write(1, MCP2317_REG_OLATB, 0x55);
    //     delay(500);
    //     mcp2317_write(0, MCP2317_REG_OLATB, 0x40);
    //     mcp2317_write(1, MCP2317_REG_OLATA, ~0x55);
    //     mcp2317_write(1, MCP2317_REG_OLATB, ~0x55);
    // }

    console_init();


    for(;;) {
        // if((systick & 0x3FF) == 0) {
        //     mcp2317_write(0, MCP2317_REG_OLATB, 0x80);
        //     mcp2317_write(1, MCP2317_REG_OLATA, 0x55);
        //     mcp2317_write(1, MCP2317_REG_OLATB, 0x55);
        // } else if((systick & 0x3FF) == 0x200) {
        //     mcp2317_write(0, MCP2317_REG_OLATB, 0x40);
        //     mcp2317_write(1, MCP2317_REG_OLATA, ~0x55);
        //     mcp2317_write(1, MCP2317_REG_OLATB, ~0x55);
        // }
        console_process();
    }
}

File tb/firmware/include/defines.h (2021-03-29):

#ifndef DEFINES_H_

#include "stm32g030xx.h"

#define CPU_FREQ 64000000UL


#define FLASH_ACR_LATENCY_0WS (0UL << FLASH_ACR_LATENCY_Pos)
#define FLASH_ACR_LATENCY_1WS (1UL << FLASH_ACR_LATENCY_Pos)
#define FLASH_ACR_LATENCY_2WS (2UL << FLASH_ACR_LATENCY_Pos)

#define RCC_CFGR_SW_HSISYS (0)
#define RCC_CFGR_SW_HSE (RCC_CFGR_SW_0)
#define RCC_CFGR_SW_PLLRCLK (RCC_CFGR_SW_1)
#define RCC_CFGR_SW_LSI (RCC_CFGR_SW_1 | RCC_CFGR_SW_0)
#define RCC_CFGR_SW_LSE (RCC_CFGR_SW_2)

#define RCC_PLLCFGR_PLLR_Val(n) (((uint32_t)(n) - 1) << RCC_PLLCFGR_PLLR_Pos)
#define RCC_PLLCFGR_PLLN_Val(n) (((uint32_t)(n)) << RCC_PLLCFGR_PLLN_Pos)
#define RCC_PLLCFGR_PLLM_Val(n) (((uint32_t)(n) - 1) << RCC_PLLCFGR_PLLM_Pos)

#define TIM_CCMR1_CC1S_OUTPUT (0 << TIM_CCMR1_CC1S_Pos)
#define TIM_CCMR1_CC2S_OUTPUT (0 << TIM_CCMR1_CC2S_Pos)
#define TIM_CCMR1_OC1M_PWM1 (TIM_CCMR1_OC1M_2 | TIM_CCMR1_OC1M_1)
#define TIM_CCMR1_OC1M_PWM2 (TIM_CCMR1_OC1M_2 | TIM_CCMR1_OC1M_1 | TIM_CCMR1_OC1M_0)
#define TIM_CCMR1_OC2M_PWM1 (TIM_CCMR1_OC2M_2 | TIM_CCMR1_OC2M_1)
#define TIM_CCMR1_OC2M_PWM2 (TIM_CCMR1_OC2M_2 | TIM_CCMR1_OC2M_1 | TIM_CCMR1_OC2M_0)

#define TIM_DCR_DBA_ARR  (11UL << TIM_DCR_DBA_Pos)
#define TIM_DCR_DBA_RCR  (12UL << TIM_DCR_DBA_Pos)
#define TIM_DCR_DBA_CCR1 (13UL << TIM_DCR_DBA_Pos)
#define TIM_DCR_DBA_CCR2 (14UL << TIM_DCR_DBA_Pos)

#define TIM_DCR_DBL_Val(n) (((uint32_t)(n) - 1) << TIM_DCR_DBL_Pos)

#define DMAMUX_CCR_REQ_TIM1_UP 25
#define DMAMUX_CCR_REQ_USART2_TX 53

#define GPIOA_AFR0_PA2_UART2_TX   (1UL << 8)
#define GPIOA_AFR0_PA3_UART2_RX   (1UL << 12)
#define GPIOA_AFR0_PA5_SPI1_SCK   (0UL << 20)
#define GPIOA_AFR0_PA6_SPI1_MISO  (0UL << 24)
#define GPIOA_AFR0_PA7_SPI1_MOSI  (0UL << 28)

#define GPIOA_AFR1_PA8_TIM1_CH1   (2UL << 0)
#define GPIOA_AFR1_PA9_TIM1_CH2   (2UL << 4)
#define GPIOA_AFR1_PA13_SWDIO     (0UL << 20)
#define GPIOA_AFR1_PA14_SWCLK     (0UL << 24)

#define GPIO_MODER_INPUT  0x0UL
#define GPIO_MODER_OUTPUT 0x1UL
#define GPIO_MODER_AF     0x2UL
#define GPIO_MODER_ANALOG 0x3UL
#define GPIO_MODER_MASK   0x3UL

#define GPIO_OTYPER_PP 0x0UL
#define GPIO_OTYPER_OD 0x1UL

#define GPIO_OSPEEDR_LOW 0x0UL
#define GPIO_OSPEEDR_MID 0x1UL
#define GPIO_OSPEEDR_HI  0x2UL
#define GPIO_OSPEEDR_VHI 0x3UL

#define GPIO_PUPDR_NONE 0x00
#define GPIO_PUPDR_PU   0x01
#define GPIO_PUPDR_PD   0x02

#define DMA_CCR_DIR_MEMORY_TO_PERIPH DMA_CCR_DIR
#define DMA_CCR_DIR_PERIPH_TO_MEMORY 0

#define DMA_CCR_MSIZE_8BITS 0
#define DMA_CCR_MSIZE_16BITS DMA_CCR_MSIZE_0
#define DMA_CCR_MSIZE_32BITS DMA_CCR_MSIZE_1

#define DMA_CCR_PSIZE_8BITS 0
#define DMA_CCR_PSIZE_16BITS DMA_CCR_PSIZE_0
#define DMA_CCR_PSIZE_32BITS DMA_CCR_PSIZE_1

#endif

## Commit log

2020-03-13 Fixed signal/pin names and tests
2020-03-17 Cleaned up circuit
2020-03-17 Marked currently failing tests
2020-04-08 Basic interrupt controller
2020-04-08 Add CRSs and interrupt controller
2020-04-13 Refactored memory circuit
2020-04-30 Introduce ImmMux to lower the number of long traces
2020-05-15 Check that pin numbers are in range
2020-05-15 Avoid printing an error when finding an end token
    We should print an error if we are not in a loop...
2020-05-15 Keep track of statement line numbers
2020-06-10 ALU schematic and pcb
    [alu.kicad_pcb, alu.sch]
2020-06-10 Logo footprints
2020-06-10 Register schematic and PCB
    [register-bank.kicad_pcb, register-bank.sch]
2020-06-10 PC schematic and PCB
    [pc.kicad_pcb, pc.sch]
2020-06-10 Memory controller schematic and PCB
    [memory.kicad_pcb, memory.sch]
2020-06-10 SRAM schematic and PCB
    [memory-ram.kicad_pcb, memory-ram.sch]
2020-06-10 Flash schematic and PCB
    [memory-rom.kicad_pcb, memory-rom.sch]
2020-06-10 Power splitter schematic and PCB
    [power-splitter.kicad_pcb, power-splitter.sch]
2020-06-10 Test bench schematic and PCB
    [test-bench.kicad_pcb, test-bench.sch]
2020-06-10 Added ~RESET to memory bus
    [memory-ram.kicad_pcb, memory-ram.sch, memory-rom.kicad_pcb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]
2020-06-11 Unified footprints
    [alu.kicad_pcb, alu.sch, memory-ram.kicad_pcb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]
2020-06-12 Added kicad project files
2020-06-12 Fully connect test headers
    [test-bench.kicad_pcb, test-bench.sch]
2020-06-12 Added filters for kicad .sch and .pro files
2020-06-12 Add more missing kicad files
2020-06-12 Added 3d model
    [memory-rom.kicad_pcb]
2020-06-12 Remoce 3d model of unpopulated components
    [memory-ram.kicad_pcb, memory-rom.kicad_pcb]
2020-06-18 Added placeholders for JLCPCB serial numbers
    [alu.kicad_pcb, memory-ram.kicad_pcb, memory-rom.kicad_pcb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]
2020-06-18 Saved plot settings
    [alu.kicad_pcb, memory-ram.kicad_pcb, memory-rom.kicad_pcb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]
2020-06-19 Added test points
    [alu.kicad_pcb, alu.sch, memory-ram.kicad_pcb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]
2020-06-20 Add J-LINK 10-pin SWD header
    [test-bench.kicad_pcb, test-bench.sch]
2020-06-20 Fix SWD pinout
    [test-bench.kicad_pcb, test-bench.sch]
2020-06-21 Generate gerbers
    [memory-rom.kicad_pcb, test-bench.kicad_pcb]
2020-06-22 Added resistors to some unused pins and a logo
    [test-bench.kicad_pcb, test-bench.sch]
2020-11-06 Minor fixes to simulated circuit
2020-12-27 Fix STM32G0 pin function
2020-12-27 Added warning about switched SWDIO and SWCLK to schematic
    Should be fixed in rev B
    [test-bench.sch]
2020-12-29 Added signal breakout board for testing
    [ribbon-viewer.kicad_pcb, ribbon-viewer.sch]
2020-12-30 Updated layout
    [ribbon-viewer.kicad_pcb]
2020-12-31 Change testpoints to pin header
    [ribbon-viewer.kicad_pcb, ribbon-viewer.sch]
2021-01-23 Finished layout
    [ribbon-viewer.kicad_pcb]
2021-02-17 Updated in-/output of registers in simulation to match real circuit
2021-02-17 Move address decoding to main circuit of simulator
2021-02-18 Fix integer overflow for random(1)
    [main.c]
2021-02-18 Read pins in chip-bank-pin (eg 1A4) format
2021-02-19 Support skipped bits in pin definition
2021-04-20 Introduce 16-bit SPI functions
2021-04-20 Let mcp2317 driver work with 16 bit data
2021-04-20 Add uart_puts
2021-04-20 Use uart_puts
2021-09-02 Sign bit is D7. Change 74LVC1G38 to 74LVC1G00
    [memory.kicad_pcb, memory.sch]
2021-09-03 Fixed LED latch
    [memory.kicad_pcb, memory.sch]
2022-01-21 Added errata to pc schematic
    [pc.sch]
2022-01-21 Added errata to ROM schematic
    [memory-rom.sch]
2022-01-21 Optimized microcode and timing circuit
2022-01-21 Correct PC connector
    [test-bench.sch]
2022-01-21 Add test circuit for SPI
2022-01-21 Make file paths relative
    [alu.kicad_pcb, memory-rom.kicad_pcb, power-splitter.kicad_pcb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]
2022-01-22 Rev B of memory-rom: switch OE and CE
    [memory-rom.kicad_pcb, memory-rom.sch]
2022-01-22 Updated gerber settings
2022-01-22 Add revision number to the front silk screen
    [memory-rom.kicad_pcb]
2022-01-24 Added draft for IO pcb
    [memory-io.kicad_pcb, memory-io.sch]
2022-01-24 Added draft of LCD pcb
    [memory-lcd.kicad_pcb, memory-lcd.sch]
2022-01-25 Added simple exit button
2022-06-08 Move Imm Mux inside opcode circuit
2022-06-08 Added start of opcode pcb
    [Imm16.kicad_sch, Imm24.kicad_sch, Imm32.kicad_sch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]
2022-06-08 Added registers pcb
    [registers.kicad_pcb, registers.kicad_sch]
2022-06-14 Improved clock circuit
2022-06-14 Fix interrupt mechanism
2022-06-16 Remove unnecessary diodes
2022-06-16 Cleanup circuit
2022-06-17 Update all to Kicad 6
    [Imm16.kicad_sch, Imm16.sch, Imm24.kicad_sch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]
2022-06-17 Ignore gerber files
2022-06-28 Started clock circuit and PCB
    [clock.kicad_pcb, clock.kicad_sch]
2022-06-30 Updated schematics and pcbs
    [Imm16.kicad_sch, Imm24.kicad_sch, Imm32.kicad_sch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]
2022-06-30 Corrected minor mistakes in circuit
2022-07-09 Updated PCBs
    [clock.kicad_pcb, step-counter.kicad_pcb, step-counter.kicad_sch]
2022-07-10 Added two LEDs
    [clock.kicad_pcb, clock.kicad_sch]
2022-07-13 Added simulation of timer circuit
2022-07-22 Updated opcode and step counter PCBs
    [opcode.kicad_pcb, step-counter.kicad_pcb, step-counter.kicad_sch]
2022-07-22 Start of memory mapped timer circuit
    [memory-timer.kicad_pcb, memory-timer.kicad_sch]
2022-09-07 Added start of adapter circuits
    [Imm16.kicad_sch, Imm24.kicad_sch, Imm32.kicad_sch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]
2022-09-07 Reorganised simulation circuit
2022-09-07 Added Jumper footprint
2022-09-26 Fix interrupt controller
2022-10-27 Added ROM + programming adapter PCBs
    [rom-programmer-adapter.kicad_pcb, rom-programmer-adapter.kicad_sch, rom.kicad_pcb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]
